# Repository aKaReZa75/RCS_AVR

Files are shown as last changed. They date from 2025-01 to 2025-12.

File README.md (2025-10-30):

# 📲 Relay Control with SMS using an AVR microcontroller  
The RCS_AVR project is an interactive, hands-on initiative focused on remote relay control via SMS.  
It includes components like a Power Supply Unit (PSU) for multiple voltage levels, a GSM Module for SMS command processing, an AVR Microcontroller (ATMEGA328) for control logic, and various inputs and outputs for seamless interaction.  
Communication occurs through protocols like UART.  
This project provides practical insights into embedded systems, covering GSM module integration, power supply management, microcontroller interfacing, remote control mechanisms, and sensor data processing. 
This project serves as an excellent platform for learning and experimenting with embedded systems, offering practical insights into real-world applications. 

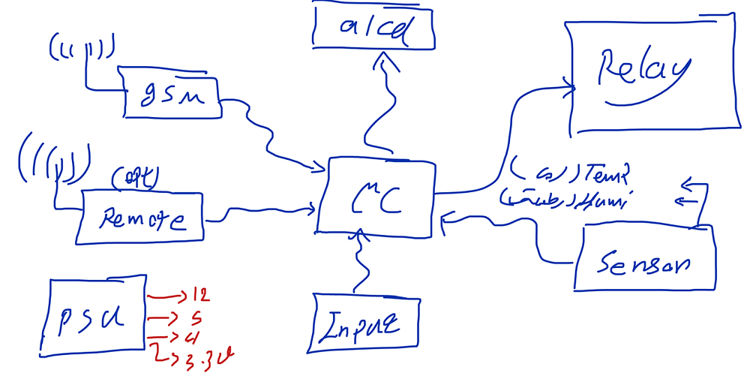
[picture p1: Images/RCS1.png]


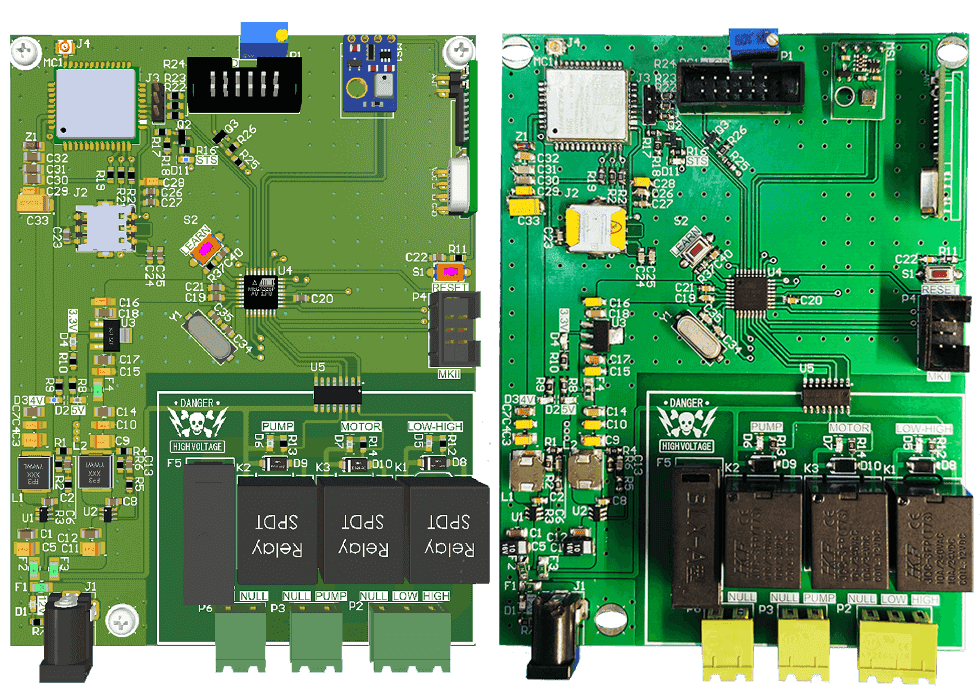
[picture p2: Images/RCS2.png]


<table>
  <tr>
  <td valign="top">
  
  > [!TIP]  
  > If you're looking to better understand how to navigate and use my GitHub repositories — including exploring their structure, downloading or cloning projects, submitting issues, and asking questions,  
  > everything you need is clearly explained in this video:  
  > [aKaReZa 95 - Programming, Git - PART B](https://youtu.be/zYiUItVFRqQ)  
  > Make sure to check it out!
  
  </td>
    <td width="360" valign="middle" style="padding: 0;">
      <a href="https://youtu.be/zYiUItVFRqQ">
       aKaReZa 95 - Programming, Git - PART B Thumbnail
      </a>
    </td>
  </td>
  </tr>

<tr>
  <td valign="top">
  
  > [!IMPORTANT]
  > Begin your embedded systems journey with clarity and purpose. This episode outlines a structured roadmap for mastering microcontrollers, communication protocols, hardware design, and project development.  
  > Learn how to choose your specialization, follow curated playlists, and engage effectively with the community—ideal for learners seeking a scalable, goal-driven path into embedded engineering.  
  > [aKaReZa 124 – Embedded Systems Roadmap](https://youtu.be/3QYfv7A7aMc)  
  > Watch it now to kickstart your journey!
  
  </td>
  <td width="360" valign="middle" style="padding: 0;">
    <a href="https://youtu.be/3QYfv7A7aMc">
      aKaReZa 124 – Embedded Systems Roadmap Thumbnail
    </a>
  </td>
</tr>

  <tr>
  <td colspan="3">

  > [!CAUTION]
  > It is absolutely critical that you carefully read every single word of this document, line by line, to ensure you don't miss any details. Nothing can be overlooked.
      
  </td>
  </tr>  
</table>

### 📋 Additional Details:
| Component | Specification |
|---|---|
| **Microcontroller** | ATMEGA328 |
| **Operating Frequency** | 16MHz |
| **Programming Language**| Embedded C |
| **Compiler** | avr-gcc |
| **Editor** | Visual Studio Code (VsCode) |
| **IDE** | PlatformIO |
| **PCB Design Software** | Altium Designer |
| **Version Control** | Git, GitHub |
| **Communication Module**| GSM (Quectel MC66) |
| **Remote Control** | RXB22 433 MHZ |
| **Display** | Character LCD 16x2 |
| **Output** | Relay, SPDT, 12V, 22X16mm, 240V/7A |
| **Temperature Sensor**  | AHT20 |
| **5V Regulator** | TPS54302 |
| **4V Regulator** | TPS54302 |
| **3.3V Regulator** | AMS1117-3.3V |

# 🔗 Resources
  Here you'll find a collection of useful links and documents related to the RCS_AVR project.  
  These resources include datasheets, tutorials, and essential tools to get you started and guide you through.
  
> [!TIP]
> The resources are detailed in the sections below.  
> To access any of them, simply click on the corresponding blue link.

- [Video PlayList](./Videos.md)
  ---  
  All educational videos related to this topic are available at this link.

- [Altium Library](https://github.com/aKaReZa75/Altium-Library)  
  ---  
   All PCB designs across all repositories and projects are built using this Altium Designer component library. It contains a wide range of verified footprints, schematic symbols, and 3D models, ensuring consistency and accuracy in PCB designs. If you're working on a new PCB, using this library will save you time and minimize errors.

- [PCB & Electronics Design Training](https://github.com/aKaReZa75/PCB)  
  ---  
  This repository is dedicated to **learning PCB design and electronics from scratch**. It covers everything from circuit theory to practical PCB layout techniques, including routing strategies, best practices, and component placement. Whether you're a beginner or an experienced designer, this resource will help you **improve your PCB design skills and create professional-quality boards**.

- [AVR Microcontroller Training](https://github.com/aKaReZa75/AVR)  
  ---  
  This repository is focused on **AVR microcontroller programming**. It covers everything from **basic to advanced concepts**, including peripheral interfacing, timers, interrupts, and communication protocols. Ideal for anyone looking to deepen their knowledge and skills with AVR microcontrollers.

- [Shopping Link](./ShoppingLink.md)  
  ---
  This document provides links to trusted suppliers where you can purchase all the essential components for this project, ensuring quality and reliability.

# 💻 How to Use Git and GitHub
To access the repository files and save them on your computer, there are two methods available:
1. **Using Git Bash and Cloning the Repository**
   - This method is more suitable for advanced users and those familiar with command-line tools.
   - By using this method, you can easily receive updates for the repository.

2. **Downloading the Repository as a ZIP file**
   - This method is simpler and suitable for users who are not comfortable with command-line tools.
   - Note that with this method, you will not automatically receive updates for the repository and will need to manually download any new updates.

## Clone using the URL.
First, open **Git Bash** :
-  Open the folder in **File Explorer** where you want the library to be stored.
-  **Right-click** inside the folder and select the option **"Open Git Bash here"** to open **Git Bash** in that directory.

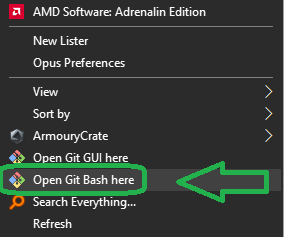
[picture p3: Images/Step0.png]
open Git Bash


> [!NOTE] 
> If you do not see the "Open Git Bash here" option, it means that Git is not installed on your system.  
> You can download and install Git from [this link](https://git-scm.com/downloads).  
> For a tutorial on how to install and use Git, check out [this video](https://youtu.be/BsykgHpmUt8).
  
-  Once **Git Bash** is open, run the following command to clone the repository:

 ```bash
git clone https://github.com/aKaReZa75/RCS_AVR
```
- You can copy the above command by either:
- Clicking on the **Copy** button on the right of the command.
- Or select the command text manually and press **Ctrl + C** to copy.
- To paste the command into your **Git Bash** terminal, use **Shift + Insert**.

Clone the Repository

- Then, press Enter to start the cloning operation and wait for the success message to appear.

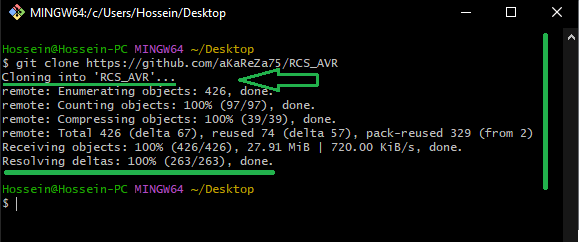
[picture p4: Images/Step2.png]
Open the Library File


> [!IMPORTANT]
> Please keep in mind that the numbers displayed in the image might vary when you perform the same actions.  
> This is because repositories are continuously being updated and expanded. Nevertheless, the overall process remains unchanged.

> [!NOTE]
> Advantage of Cloning the Repository:  
> - **Receiving Updates:** By cloning the repository, you can easily and automatically receive new updates.  
> - **Version Control:** Using Git allows you to track changes and revert to previous versions.  
> - **Team Collaboration:** If you are working on a project with a team, you can easily sync changes from team members and collaborate more efficiently.  

## Download Zip
If you prefer not to use Git Bash or the command line, you can download the repository directly from GitHub as a ZIP file.  
Follow these steps:  
1. Navigate to the GitHub repository page and Locate the Code button:
   - On the main page of the repository, you will see a green Code button near the top right corner.

2. Download the repository:
   - Click the Code button to open a dropdown menu.
   - Select Download ZIP from the menu.

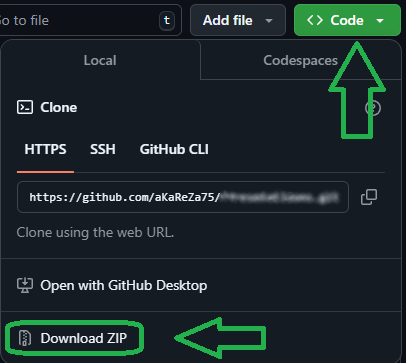
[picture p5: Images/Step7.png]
Download Zip
    

3. Save the ZIP file:
   - Choose a location on your computer to save the ZIP file and click Save.

4. Extract the ZIP file:
   - Navigate to the folder where you saved the ZIP file.
   - Right-click on the ZIP file and select Extract All... (Windows) or use your preferred extraction tool.
   - Choose a destination folder and extract the contents.

5. Access the repository:
   - Once extracted, you can access the repository files in the destination folder.

> [!IMPORTANT]
> - No Updates: Keep in mind that downloading the repository as a ZIP file does not allow you to receive updates.    
>   If the repository is updated, you will need to download it again manually.  
> - Ease of Use: This method is simpler and suitable for users who are not comfortable with Git or command-line tools.

# 📝 How to Ask Questions
If you have any questions or issues, you can raise them through the **"Issues"** section of this repository. Here's how you can do it:  

1. Navigate to the **"Issues"** tab at the top of the repository page.  

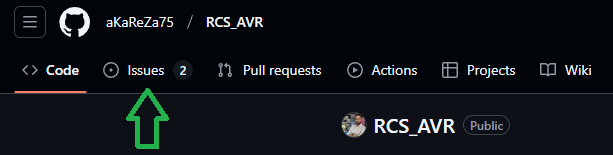
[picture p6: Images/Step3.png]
Issues
  

2. Click on the **"New Issue"** button.  
   
  New Issue

3. In the **Title** field, write a short summary of your issue or question.  

4. In the "Description" field, detail your question or issue as thoroughly as possible. You can use text formatting, attach files, and assign the issue to someone if needed. You can also use text formatting (like bullet points or code snippets) for better readability.  

5. Optionally, you can add **labels**, **type**, **projects**, or **milestones** to your issue for better categorization.  

6. Click on the **"Submit new issue"** button to post your question or issue.
   
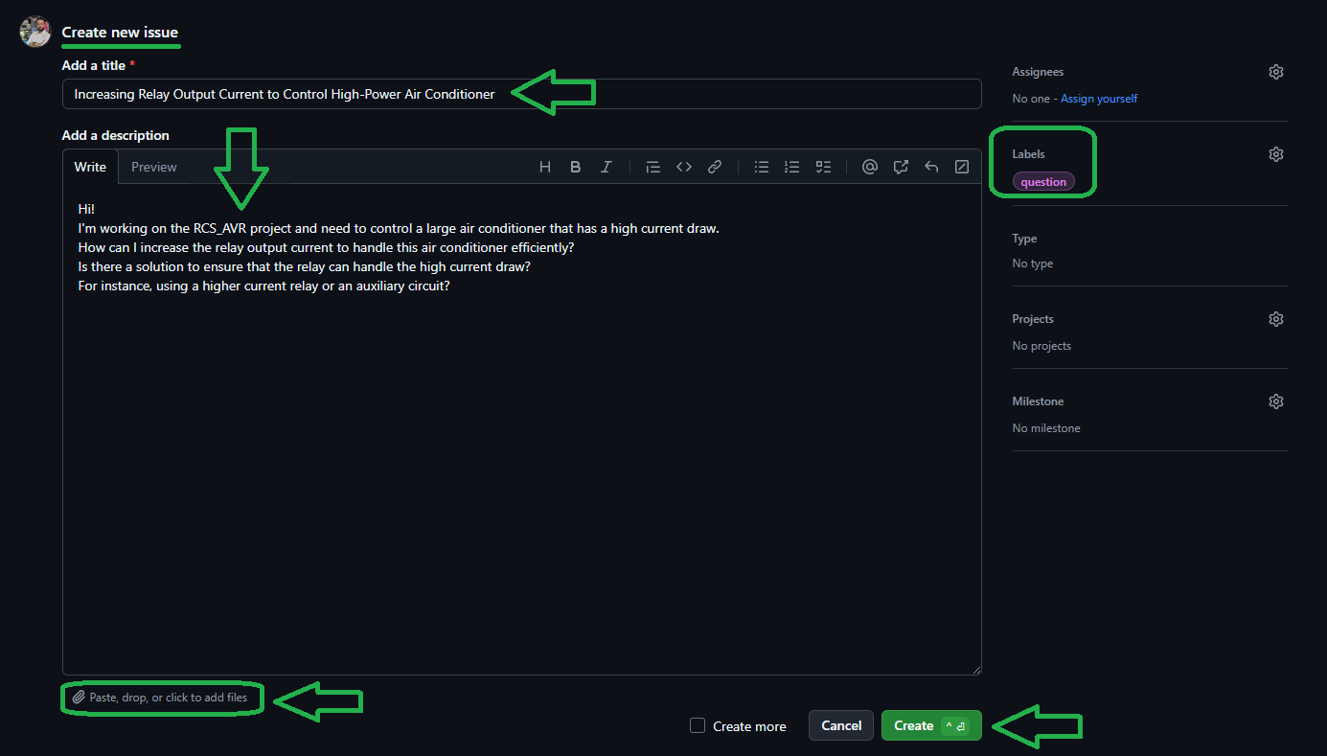
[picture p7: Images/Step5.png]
Submeet New Issue
  

I will review and respond to your issue as soon as possible. Your participation helps improve the repository for everyone!  

> [!TIP]
> - Before creating a new issue, please check the **"Closed"** section to see if your question has already been answered.  
>   Closed section  
> - Write your question clearly and respectfully to ensure a faster and better response.  
> - While the examples provided above are in English, feel free to ask your questions in **Persian (فارسی)** as well.  
> - There is no difference in how they will be handled!  

> [!NOTE]
> Pages and interfaces may change over time, but the steps to create an issue generally remain the same.

# 🤝 Contributing to the Repository
To contribute to this repository, please follow these steps:
1. **Fork the Repository**  
2. **Clone the Forked Repository**  
3. **Create a New Branch**  
4. **Make Your Changes**  
5. **Commit Your Changes**  
6. **Push Your Changes to Your Forked Repository**  
7. **Submit a Pull Request (PR)**  

> [!NOTE]
> Please ensure your pull request includes a clear description of the changes you’ve made.
> Once submitted, I will review your contribution and provide feedback if necessary.

# 🌟 Support Me
If you found this repository useful:
- Subscribe to my [YouTube Channel](https://www.youtube.com/@aKaReZa75).
- Share this repository with others.
- Give this repository and my other repositories a star.
- Follow my [GitHub account](https://github.com/aKaReZa75).

# 📜 License
This project is licensed under the GPL-3.0 License. This license grants you the freedom to use, modify, and distribute the project as long as you:
- Credit the original authors: Give proper attribution to the original creators.
- Disclose source code: If you distribute a modified version, you must make the source code available under the same GPL license.
- Maintain the same license: When you distribute derivative works, they must be licensed under the GPL-3.0 too.
- Feel free to use it in your projects, but make sure to comply with the terms of this license.
  
# ✉️ Contact Me
Feel free to reach out to me through any of the following platforms:
- 📧 [Email: aKaReZa75@gmail.com](mailto:aKaReZa75@gmail.com)
- 🎥 [YouTube: @aKaReZa75](https://www.youtube.com/@aKaReZa75)
- 💼 [LinkedIn: @akareza75](https://www.linkedin.com/in/akareza75)

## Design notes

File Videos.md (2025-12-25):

# Videos
 In this document, you will find videos related to the RCS_AVR project along with their descriptions, which are divided into three categories: 
 - **Hardware design videos**
 - **Assembly and soldering videos**
 - **Coding and testing videos**

```plaintext
RCS, AVR Project
├── PCB
│   ├── [aKaReZa 70 - RCS, AVR - PART A]
│   │     ├─ Kickoff — Conceptual design, enclosure, Git/GitHub.
│   │     └─ Schematic — Altium Designer introduction and setup.
│   │
│   ├── [aKaReZa 71 - RCS, AVR - PART B]
│   │     ├─ Power Supply — 12V, 5V, 4V, 3.3V design.
│   │     └─ Safety — Fusing and voltage indicators.
│   │
│   ├── [aKaReZa 72 - RCS, AVR - PART C]
│   │     ├─ Collaboration — Issues, Pull Requests, Git tools.
│   │     └─ Power — Final regulator setup and LED resistors.
│   │
│   ├── [aKaReZa 73 - RCS, AVR - PART D]
│   │     ├─ Logic & Outputs — ATMega328, Reset, Relays, ULN2003.
│   │     ├─ Protection — Flywheel diode and LED indicators.
│   │     └─ Structure — Hierarchical design + library file export.
│   │
│   ├── [aKaReZa 75 - RCS, AVR - PART E]
│   │     ├─ LCD & Harness — Alphanumeric display and Harness tool.
│   │     ├─ GSM — SIMCard, UART protocol, filters, network LED.
│   │     └─ Review — GitHub Pull Requests and GSM tips.
│   │
│   ├── [aKaReZa 79 - RCS, AVR - PART F]
│   │     ├─ Input — 220V detection and signal handling.
│   │     ├─ Remote Control — Section creation and error fixes.
│   │     └─ Integration — Board shape design + Hamibash feature.
│   │
│   ├── [aKaReZa 81 - RCS, AVR - PART G]
│   │     ├─ Schematic Updates — GitHub issues and fixes.
│   │     ├─ PCB — Component placement and routing.
│   │     └─ Capacitors — Placement technique and performance tip.
│   │
│   └── [aKaReZa 83 - RCS, AVR - PART H]
│         ├─ Routing — Completion and optimization.
│         ├─ Tools — Polygon, Teardrops, Via Stitching.
│         └─ Mounting — Screw placement and final fixes.
│ 
├── Soldering
│   ├── [aKaReZa 100 - RCS, AVR - PART A]
│   │     ├─ Sections — 12V, 5V, 3.3V regulators.
│   │     ├─ MCU — ATMEGA soldering + relay + LCD.
│   │     └─ Testing — Segment-wise validation.
│   │
│   └── [aKaReZa 104 - RCS, AVR - PART B]
│         ├─ LCD Connector — Precision soldering tips.
│         ├─ Components — 4V reg, Quectel M66, SIM filters.
│         └─ Final Test — Complete module evaluation.
│ 
└── Programming
    ├── [aKaReZa 106 - RCS, AVR - PART I]
    │     ├─ PlatformIO — Project setup and structure.
    │     ├─ LCD — HomePage design and initialization.
    │     ├─ Relays — Output pin config and tests.
    │     └─ Control — Modular output handling logic.
    │
    ├── [aKaReZa 109 - RCS, AVR - PART J]
    │     ├─ Control — Output status display on LCD.
    │     ├─ GSM — Signal strength and registration via M66.
    │     ├─ Logic — State machine design.
    │     └─ Interface — Graphical LCD menu implementation.
    │
    ├── [aKaReZa 119 - RCS, AVR - PART K]
    │     ├─ Libraries — Project structure and GSM setup.
    │     ├─ SMS Rx — Parsing incoming messages.
    │     ├─ Format — Suggested SMS command syntax.
    │     ├─ Control — Output switching via SMS.
    │     ├─ Reply — Sending confirmation messages.
    │     ├─ Case Handling — `str_toUpper()` for flexibility.
    │     └─ Stability — Debugging and system reliability.
    │
    ├── [aKaReZa 125 - RCS, AVR - PART L]
    │     ├─ Git — Branch creation and version control.
    │     ├─ State Machine — System behavior management.
    │     ├─ Scheduler — Task configuration and execution.
    │     ├─ Tasks — Output and display routines.
    │     ├─ GSM States — One-time operations and transitions.
    │     └─ Deployment — Pushing changes to GitHub.
    │
    ├── [aKaReZa 128 - RCS, AVR - PART N]
    │   ├─ GSM_Reset — Definition and safe reinitialization flow.
    │   ├─ GSM_StartUp — Sequencing and non-blocking checks.
    │   ├─ LCD Feedback — Live state reflection on display.
    │   ├─ GSM_Init — Resource setup and readiness validation.
    │   └─ GSM_Idle — Event-driven loop and transition rules.
    │
    └── [aKaReZa 132 - RCS, AVR - PART O]
        ├─ Detection — Finding new SMS messages from GSM.
        ├─ GSM_SMS_ParseNumber — Extracting message index.
        ├─ GSM_SMS_ReadContent — Getting sender number and text.
        ├─ GSM_SMS_SendSMS — Reply SMS state machine.
        ├─ LCD — Busy icon, Welcome Page redesign, FW version.
        ├─ Code — Readability and structure improvements.
        └─ Git — Introduction to git merge workflow.
```

## PCB Desing Videos
<table style="border-collapse: collapse;">
  <tr>
    <td valign="top" style="padding: 0 10px;">
      <h3 style="margin: 0;">
        <a href="https://youtu.be/KLH8E3yOOMw">aKaReZa 70 – RCS, AVR - PART A</a>
      </h3>
      <p style="margin: 8px 0 0;">
        This first video in the series covers designing a project from idea to final product, including conceptual design, casing selection, schematic creation in Altium Designer, and more.
      </p>
    </td>
    <td width="360" valign="top" style="padding: 0;">
      <a href="https://youtu.be/KLH8E3yOOMw">
        aKaReZa 70 – RCS, AVR - PART A Thumbnail
      </a>
    </td>
  </tr>

  <tr>
    <td valign="top" style="padding: 0 10px;">
      <h3 style="margin: 0;">
        <a href="https://youtu.be/-EyT4b3-hQU">aKaReZa 71 – RCS, AVR - PART B</a>
      </h3>
      <p style="margin: 8px 0 0;">
        In this video, we design a 12-5-4-3.3V power supply, add fuses, and include voltage indicators.
      </p>
    </td>
    <td width="360" valign="top" style="padding: 0;">
      <a href="https://youtu.be/-EyT4b3-hQU">
        aKaReZa 71 – RCS, AVR - PART B Thumbnail
      </a>
    </td>
  </tr>

  <tr>
    <td valign="top" style="padding: 0 10px;">
      <h3 style="margin: 0;">
        <a href="https://youtu.be/bh53Z6KH728">aKaReZa 72 – RCS, AVR - PART C</a>
      </h3>
      <p style="margin: 8px 0 0;">
        In this video, we review all your Issues and Pull Requests, introduce some useful software, complete the project's power supply section, and discuss upcoming channel content and plans.
      </p>
    </td>
    <td width="360" valign="top" style="padding: 0;">
      <a href="https://youtu.be/bh53Z6KH728">
        aKaReZa 72 – RCS, AVR - PART C Thumbnail
      </a>
    </td>
  </tr>

  <tr>
    <td valign="top" style="padding: 0 10px;">
      <h3 style="margin: 0;">
        <a href="https://youtu.be/vWiSh-8D4kY">aKaReZa 73 – RCS, AVR - PART D</a>
      </h3>
      <p style="margin: 8px 0 0;">
        In this video, after designing the controller and output sections, we learn hierarchical design, create the project hierarchically, and finally generate the project's library file.
      </p>
    </td>
    <td width="360" valign="top" style="padding: 0;">
      <a href="https://youtu.be/vWiSh-8D4kY">
        aKaReZa 73 – RCS, AVR - PART D Thumbnail
      </a>
    </td>
  </tr>

  <tr>
    <td valign="top" style="padding: 0 10px;">
      <h3 style="margin: 0;">
        <a href="https://youtu.be/V0r4XVZA-bk">aKaReZa 75 – RCS, AVR - PART E</a>
      </h3>
      <p style="margin: 8px 0 0;">
        In this video, we cover using character LCDs, the Harness tool in Altium Designer, identifying VCC, VEE, VDD, and VSS pins, connecting a SIM card and UART protocol to a GSM module, adding power filters and a network status LED to the GSM module, and reviewing some GSM module tips. Additionally, we check the raised Pull Requests and Issues.
      </p>
    </td>
    <td width="360" valign="top" style="padding: 0;">
      <a href="https://youtu.be/V0r4XVZA-bk">
        aKaReZa 75 – RCS, AVR - PART E Thumbnail
      </a>
    </td>
  </tr>

  <tr>
    <td valign="top" style="padding: 0 10px;">
      <h3 style="margin: 0;">
        <a href="https://youtu.be/U1JYVCcn27k">aKaReZa 79 – RCS, AVR - PART F</a>
      </h3>
      <p style="margin: 8px 0 0;">
        In this video, we review raised Pull Requests and Issues, organize the project, design the input section and 220V signal detection, design the code-learn remote section, fix errors, resize the board to fit the casing, introduce the "Hami Bash" section, and discuss the idea of casing installation.
      </p>
    </td>
    <td width="360" valign="top" style="padding: 0;">
      <a href="https://youtu.be/U1JYVCcn27k">
        aKaReZa 79 – RCS, AVR - PART F Thumbnail
      </a>
    </td>
  </tr>

  <tr>
    <td valign="top" style="padding: 0 10px;">
      <h3 style="margin: 0;">
        <a href="https://youtu.be/6VrP90s_HFc">aKaReZa 81 – RCS, AVR - PART G</a>
      </h3>
      <p style="margin: 8px 0 0;">
        In this video, we address the issues raised on GitHub, make several schematic changes, place components in the PCB environment, route several sections, and learn a crucial tip about capacitor placement.
      </p>
    </td>
    <td width="360" valign="top" style="padding: 0;">
      <a href="https://youtu.be/6VrP90s_HFc">
        aKaReZa 81 – RCS, AVR - PART G Thumbnail
      </a>
    </td>
  </tr>

  <tr>
    <td valign="top" style="padding: 0 10px;">
      <h3 style="margin: 0;">
        <a href="https://youtu.be/ByZ2kSmf6VU">aKaReZa 83 – RCS, AVR - PART H</a>
      </h3>
      <p style="margin: 8px 0 0;">
        In this video, we continue routing the board. After completing the routes, we learn how to strengthen power paths, place screws on the board, and use the Polygon, Teardrops, and Via stitching tools.
      </p>
    </td>
    <td width="360" valign="top" style="padding: 0;">
      <a href="https://youtu.be/ByZ2kSmf6VU">
        aKaReZa 83 – RCS, AVR - PART H Thumbnail
      </a>
    </td>
  </tr>

  <tr>
    <td valign="top" style="padding: 0 10px;">
      <h3 style="margin: 0;">
        <a href="https://youtu.be/FoJUFKjwWjk">aKaReZa 98 – PCB, Ordering</a>
      </h3>
      <p style="margin: 8px 0 0;">
        In this video, explore essential steps for ordering PCB, from fixing issues before printing, reviewing design rules, error troubleshooting, professional documentation, and learning about local companies and Cheap Project group for seamless PCB manufacturing.
      </p>
    </td>
    <td width="360" valign="top">
      <a href="https://youtu.be/FoJUFKjwWjk">
        aKaReZa 98 – PCB, Ordering Thumbnail
      </a>
    </td>
  </tr>  
</table>

## Assembly and soldering videos
<table style="border-collapse: collapse;">
  <tr>
    <td valign="top" style="padding: 0 10px;">
      <h3 style="margin: 0;">
        <a href="https://youtu.be/UuL0Z89b1r0">aKaReZa 100 – Repair, RCS, AVR - PART A</a>
      </h3>
      <p style="margin: 8px 0 0;">
        Learn the full soldering and assembly process of the RCS-AVR board. This video walks you through every step, including soldering power inputs, voltage regulators (12V, 5V, 3.3V), microcontroller placement, relay and LCD installation, and performing circuit tests after each phase to ensure proper functionality. A must-watch for anyone wanting practical experience in microcontroller board repair and troubleshooting.
      </p>
    </td>
    <td width="360" valign="top">
      <a href="https://youtu.be/UuL0Z89b1r0">
        aKaReZa 100 – Repair, RCS, AVR - PART A Thumbnail
      </a>
    </td>
  </tr>

  <tr>
    <td valign="top" style="padding: 0 10px;">
      <h3 style="margin: 0;">
        <a href="https://youtu.be/i9ef0sJyjoc">aKaReZa 104 – Repair, RCS AVR Soldering - PART B</a>
      </h3>
      <p style="margin: 8px 0 0;">
        Continue soldering the RCS-AVR project with a focus on communication modules. This video covers LCD connector soldering, 4V regulator installation, Quectel M66 module assembly, SIM card connector setup, remaining component soldering, and final system testing to ensure everything functions correctly. Perfect for microcontroller board assembly and troubleshooting enthusiasts.
      </p>
    </td>
    <td width="360" valign="top">
      <a href="https://youtu.be/i9ef0sJyjoc">
        aKaReZa 104 – Repair, RCS AVR Soldering - PART B Thumbnail
      </a>
    </td>
  </tr> 
</table>

## Coding and testing videos
<table style="border-collapse: collapse;">
  <tr>
    <td valign="top" style="padding: 0 10px;">
      <h3 style="margin: 0;">
        <a href="https://youtu.be/397Jk0z9aTY">aKaReZa 106 – RCS, AVR - PART I</a>
      </h3>
      <p style="margin: 8px 0 0;">
        Start coding the RCS-AVR project using PlatformIO, with a focus on LCD initialization, homepage design, relay control, and hardware interaction. This video lays the groundwork for structured, modular AVR programming tailored to practical embedded systems development.
      </p>
    </td>
    <td width="360" valign="top">
      <a href="https://youtu.be/397Jk0z9aTY">
        aKaReZa 106 – RCS, AVR - PART I Thumbnail
      </a>
    </td>
  </tr>

  <tr>
    <td valign="top" style="padding: 0 10px;">
      <h3 style="margin: 0;">
        <a href="https://youtu.be/tSlz7DpWGOs">aKaReZa 109 – RCS, AVR - PART J</a>
      </h3>
      <p style="margin: 8px 0 0;">
        Advance the RCS-AVR project by implementing output control, reading signal strength, managing network registration, and designing LCD menus. This video explores state machines, real-time status display, and software-hardware interaction—ideal for building smart embedded systems.
      </p>
    </td>
    <td width="360" valign="top">
      <a href="https://youtu.be/tSlz7DpWGOs">
        aKaReZa 109 – RCS, AVR - PART J Thumbnail
      </a>
    </td>
  </tr>

  <tr>
    <td valign="top" style="padding: 0 10px;">
      <h3 style="margin: 0;">
        <a href="https://youtu.be/OboAPzh3QSU">aKaReZa 119 – RCS, AVR - PART K</a>
      </h3>
      <p style="margin: 8px 0 0;">
        Build SMS-based control systems with AVR and the Quectel M66 module. This video covers message parsing, output control, reply generation, and case-insensitive command handling using <code>str_toUpper()</code>—a practical guide for robust GSM integration in embedded projects.
      </p>
    </td>
    <td width="360" valign="top">
      <a href="https://youtu.be/OboAPzh3QSU">
        aKaReZa 119 – RCS, AVR - PART K Thumbnail
      </a>
    </td>

  <tr>
    <td valign="top" style="padding: 0 10px;">
      <h3 style="margin: 0;">
        <a href="https://youtu.be/RPZP1AIJVvo">aKaReZa 125 – RCS, AVR - PART L</a>
      </h3>
      <p style="margin: 8px 0 0;">
        Advance your embedded software development workflow with Git and structured logic. This episode introduces Git branching for safe feature development, implements a robust State Machine, configures a Scheduler, and defines tasks for output and display control. It also reviews GSM module states and one-time operations, culminating in a clean GitHub push—ideal for building scalable, maintainable AVR-based systems.
      </p>
    </td>
    <td width="360" valign="top">
      <a href="https://youtu.be/RPZP1AIJVvo">
        aKaReZa 125 – RCS, AVR - PART L Thumbnail
      </a>
    </td>
  </tr>

  <tr style="background-color: #f9f9f9;">
    <td valign="top" style="padding: 0 10px;">
      <h3 style="margin: 0;">
        <a href="https://youtu.be/RqF51kzmc10">aKaReZa 128 – RCS, AVR - PART N</a>
      </h3>
      <p style="margin: 8px 0 0;">
        Deepen your understanding of <strong>State Machines in embedded systems</strong> with this AVR-based RCS project episode. You’ll learn how to implement and manage <strong>GSM_Reset, GSM_StartUp, GSM_Init, and GSM_Idle states</strong>, while reflecting transitions on the LCD. The tutorial emphasizes <strong>non-blocking code design principles</strong>, making it a crucial step toward building smarter, more reliable GSM-driven control systems.
      </p>
    </td>
    <td width="360" valign="top">
      <a href="https://youtu.be/RqF51kzmc10">
        aKaReZa 128 – RCS, AVR - PART N Thumbnail
      </a>
    </td>
  </tr>

  <tr style="background-color: #f9f9f9;">
    <td valign="top" style="padding: 0 10px;">
      <h3 style="margin: 0;">
        <a href="https://youtu.be/P0FgmPWP3M4">aKaReZa 132 – RCS, AVR - PART O</a>
      </h3>
      <p style="margin: 8px 0 0;">
        Implement fully non‑blocking <strong>SMS receive/send state machines</strong> in the RCS‑AVR project. This episode walks through detecting new messages, parsing the SMS index, extracting the sender’s number and text, and sending replies through the GSM module. You’ll also enhance the LCD interface with <strong>custom characters</strong>, redesign the <strong>Welcome Page</strong>, display the firmware version, and learn how to integrate changes using <strong>git merge</strong> for a cleaner workflow.
      </p>
    </td>
    <td width="360" valign="middle">
      <a href="https://youtu.be/P0FgmPWP3M4">
        aKaReZa 132 – RCS, AVR - PART O Thumbnail
      </a>
    </td>
  </tr>
  
</table>

# 🌟 Support Me
If you found this repository useful:
- Subscribe to my [YouTube Channel](https://www.youtube.com/@aKaReZa75).
- Share this repository with others.
- Give this repository and my other repositories a star.
- Follow my [GitHub account](https://github.com/aKaReZa75).

# ✉️ Contact Me
Feel free to reach out to me through any of the following platforms:
- 📧 [Email: aKaReZa75@gmail.com](mailto:aKaReZa75@gmail.com)
- 🎥 [YouTube: @aKaReZa75](https://www.youtube.com/@aKaReZa75)
- 💼 [LinkedIn: @akareza75](https://www.linkedin.com/in/akareza75)

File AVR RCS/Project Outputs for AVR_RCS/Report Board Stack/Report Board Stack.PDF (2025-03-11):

# Board Stack Report

Stack Up | Layer Stack
Layer | Board Layer Stack | Name | Material | Thickness Constant Dk | | | Coverlay expansion | Orientation | Copper Orientation
1 | | Top Overlay | | 0mm
2 | | Top Solder | Solder Resist | 0.01016mm | 3.5 | 3.5 0mm
3 | | Top Layer | | 0.03556mm | | | | BodyUp | Above
4 | | Dielectric 1 | FR-4 | 1.5mm | 4.8 | 4.8
5 | | Bottom Layer | | 0.03556mm | | | | BodyDown | Below
6 | | Bottom Solder | Solder Resist | 0.01016mm | 3.5 | 3.5 0mm
7 | | Bottom Overlay | | 0mm
| Height : 1.59144mm

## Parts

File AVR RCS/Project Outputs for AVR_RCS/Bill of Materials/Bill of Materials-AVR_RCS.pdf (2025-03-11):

Altium Limited Confidential | 3/11/2025 | Page 1

# Bill of Materials

Title: Bill of Materials for Project [AVR_RCS.PrjPcb] (No PCB Document Selected) Project: AVR RCS
Company github.com/aKaReZa75
Variant: None
Revision: 1.0
Inflow | LibRef | Footprint | Value | Rating | Package | Type | Description | Comment | Quantity
inflow? | Cap_Multi_SMD_100nF_0805 | CAP 0805/2012 | 100n | 50V | 0805 | MultiLayer | Bipolar ceramic capacitor SMD | 100n | 8
inflow? | Cap_Multi_SMD_100nF_1206 | CAP 1206/3216 | 100n | 50V | 1206 | MultiLayer | Bipolar ceramic capacitor SMD | 100n | 7
inflow? | Cap_Multi_SMD_0805 | CAP 0805/2012 | 22p | Rating? | 0805 | MultiLayer | Bipolar ceramic capacitor SMD | 22p | 2
inflow? | Cap_Multi_SMD_0805 | CAP 0805/2012 | 33p | Rating? | 0805 | MultiLayer | Bipolar ceramic capacitor SMD | 33p | 4
inflow? | Cap_Multi_SMD_0805 | CAP 0805/2012 | 68p | Rating? | 0805 | MultiLayer | Bipolar ceramic capacitor SMD | 68p | 2
inflow? | Cap_Multi_SMD_1206 | CAP 1206/3216 | 10p | 50V | 1206 | MultiLayer | Bipolar ceramic capacitor SMD | 10p | 1
inflow? | Cap_Multi_SMD_1206 | CAP 1206/3216 | 33p | 50V | 1206 | MultiLayer | Bipolar ceramic capacitor SMD | 33p | 1
inflow? | Cap_Tantalum | SMT_C_Tantalum_A | 1u | 6.3V | SMD-A | Tantalum | Tantalum Capacitor,TAJ Series-SMD | 1u | 2
inflow? | Cap_Tantalum | SMT_C_Tantalum_A | 10u | 6.3v | Package? | Tantalum | Tantalum Capacitor,TAJ Series-SMD | 10u | 3
inflow? | Cap_Tantalum | SMT_C_Tantalum_B | 10u | 25v | Package? | Tantalum | Tantalum Capacitor,TAJ Series-SMD | 10u | 2
inflow? | Cap_Tantalum | SMT_C_Tantalum_A | 22u | 6.3v | Package? | Tantalum | Tantalum Capacitor,TAJ Series-SMD | 22u | 1
inflow? | Cap_Tantalum | SMT_C_Tantalum_B | 47u | 6.3v | Package? | Tantalum | Tantalum Capacitor,TAJ Series-SMD | 47u | 2
inflow? | Cap_Tantalum | SMT_C_Tantalum_C | 100u | 6.3V | SMD-C | Tantalum | Tantalum Capacitor,TAJ Series-SMD | 100u | 1
7152 | Con_MPH_3x1_V_THT_2.54 | HDR_THT_3M_2.54mm | 3 | Rating? | Package? | Type? | Header, single row, 3 pin | 3 | 1
inflow? | Con_Power_2 | Phoenix_2PIN_RA_P5.08mm | 2'Pin | Rating? | Package? | Type? | Power Connector 2'Pin | 2'Pin | 2
inflow? | Con_Power_3 | Phoenix_3PIN_RA_P5.08mm | Value? | 3b | Dip | Type? | Power Connector 3'Pin | Value? | 1
6127 | Con_Power_Jack | Power Jack BIG | Female | Rating? | Package? | Type? | Power Jack | Female | 1
inflow? | Con_Prog_MKII_ISP | IDC_2X3 | 3x2 | Rating? | Package? | Type? | 6 Pin Standard ISP Header For MKII | 3x2 | 1
inflow? | Con_RF_U.FL | IPEX-3x3mm | U.FL | Rating? | SMD | RF | U.FL | U.FL | 1
inflow? | Con_Socket_SimCard_1 | GCT_SIM8051_Plastik | 6'Pin | Rating? | SMD | Nano | Nano SimCard Holder 6P | 6'Pin | 1
1506 | IC_Driver_ULN2003 | SO16_M | ULN2003 | Rating? | SO-16 | Driver | Seven darlington array drivers | ULN2003 | 1
inflow? | IC_MCU_ATmega328P_SMD | ATMEGA328 | ATmega328P Rating? | | Package? | Type? | 8-Bit AVR Microcontroller with 32K | ATmega328P | 1
5217 | IC_Reg_AMS1117_3.3 | SOT223_M | 3.3V | 1A | SOT223 | LDO | 1'A Positive voltage regulator | 3.3V | 1
inflow? | IC_Reg_TPS54302 | TPS54302 | Value? | S | SOT-23-6 | Switching | 3'A Synchronous Step-Down Converter | Value? | 2
inflow? | Ind_SMD | L_7 | 10u | 3.8A | Package? | Type? | Inductor | 10u | 2
inflow? | ModSen_AHT20 | AHT20 | AHT20 | Rating? | Dip | Air T&H | Air Temperature and Humidity Sensor | AHT20 | 1
inflow? | ModSen_Com_M66 | m66 | M66 | Rating? | Dip | GSM-GPRS | Quectel GSM/GPRS Module | M66 | 1
8251 | ModSen_Com_RXB22_433 | RF_ETRXB | RXB22 | 433M | Dip | Learning | JMR RXB22 433MHz ASK | RXB22 | 1
8116 | ModSen_LCD_CH_16x2_Box | BOX-HDR-2x6-2.54mm-S | 16x2 | Rating? | Dip | Alphanumeric | Alphanumeric LCD character | 16x2 | 1
inflow? | Other_Elec_Fuse_SMD | 1206_F | 0.5A | Rating? | 1206 | Fast | Short circiut protection | 0.5A | 1
inflow? | Other_Elec_Fuse_SMD | 1206_F | 1A | Rating? | 1206 | Fast | Short circiut protection | 1A | 1
inflow? | Other_Elec_Fuse_SMD | 1206_F | 2A | Rating? | 1206 | Fast | Short circiut protection | 2A | 1
inflow? | Other_Elec_Fuse_SMD | 1206_F | 3A | Rating? | 1206 | Fast | Short circiut protection | 3A | 1
inflow? | Other_Elec_Fuse_THT | FUSE_BLX_20x5 | 5A | Rating? | Package? | Type? | Short circiut protection | 5A | 1
inflow? | Other_Elec_Xtal_SMD | Crystal SMD | 12M | Rating? | SMD | Quartz | Crystal Oscillator | 12M | 1
8243 | Other_Mech_Screw | SCREW-M3 | M3 | Rating? | Package? | Screw | Board Screw With Spacer | M3 | 3
inflow? | Res_Multi | Multi turn 01 | 10K | Rating? | Package? | Type? | Multi Turn | 10K | 1
inflow? | Res_SMD_0805 | RES 0805 (2012X06L) | 1K | 0.125W | 0805 | 10% | Resistor | 1K | 3
inflow? | Res_SMD_0805 | RES 0805 (2012X06L) | 1.8K | 0.125W | 0805 | 10% | Resistor | 1.8K | 5
inflow? | Res_SMD_0805 | RES 0805 (2012X06L) | 4.7K | 0.125W | 0805 | 10% | Resistor | 4.7K | 4
inflow? | Res_SMD_0805 | RES 0805 (2012X06L) | 5.6K | 0.125W | 0805 | 10% | Resistor | 5.6K | 1
inflow? | Res_SMD_0805 | RES 0805 (2012X06L) | 10K | 0.125W | 0805 | 10% | Resistor | 10K | 2
inflow? | Res_SMD_0805 | RES 0805 (2012X06L) | 13.7K | 0.125W | 0805 | 1% | Resistor | 13.7K | 1
inflow? | Res_SMD_0805 | RES 0805 (2012X06L) | 17.8K | 0.125W | 0805 | 1% | Resistor | 17.8K | 1
inflow? | Res_SMD_0805 | RES 0805 (2012X06L) | 22b | 0.125W | 0805 | 10% | Resistor | 22b | 3
inflow? | Res_SMD_0805 | RES 0805 (2012X06L) | 47K | 0.125W | 0805 | 10% | Resistor | 47K | 2
inflow? | Res_SMD_0805 | RES 0805 (2012X06L) | 49.9b | 0.125W | 0805 | 1% | Resistor | 49.9b | 2
inflow? | Res_SMD_0805 | RES 0805 (2012X06L) | 100b | 0.125W | 0805 | 10% | Resistor | 100b | 2
inflow? | Res_SMD_0805 | RES 0805 (2012X06L) | 100K | 0.125W | 0805 | 1% | Resistor | 100K | 2
inflow? | Res_SMD_0805 | RES 0805 (2012X06L) | 220b | 0.125W | 0805 | 10% | Resistor | 220b | 1
inflow? | Res_SMD_0805 | RES 0805 (2012X06L) | 680b | 0.125W | 0805 | 10% | Resistor | 680b | 1
inflow? | Semi_BJT_BC817 | SOT23_N | NPN | Rating? | Package? | Type? | NPN General purpose Transistor | NPN | 2
inflow? | Semi_Diod_Sch_1N5819_SMD | 430X270D | 1N5819 | Rating? | SMA | Schottky | Schottky Rectifiers | 1N5819 | 3
inflow? | Semi_Diod_TVS_SMF05 | SC70-5_N | SMF-05 | Rating? | SC70-5 | TVS | TVS Diode Array | SMF-05 | 1
inflow? | Semi_Diod_Zener_SMD | SOD80, LL-34 | 5.1V | 0.5W | SOD-80 | Zener | Zener Diode | 5.1V | 1
inflow? | Semi_LED_SMD | LED 0805/2012 BLUE | Blue | Rating? | Package? | LED | LED | Blue | 2
inflow? | Semi_LED_SMD | LED 0805/2012 GREEN | Green | Rating? | Package? | LED | LED | Green | 4
inflow? | Semi_LED_SMD | LED 0805/2012 RED | Red | Rating? | Package? | LED | LED | Red | 1
inflow? | Semi_LED_SMD | LED 0805/2012 YELLOW | Yellow | Rating? | Package? | LED | LED | Yellow | 1
8260 | SW_PushButton_2_SMD | SW_PB_SMD_2PIN_SPST_6X | PB | 2b | SMD | Vertical | SMT Tactile ‎Switch | PB | 2
inflow? | SW_Relay_SPDT | Relay 18.85x15.35x15.70 | 12V | Rating? | Dip | SPDT | SPDT Relay | 12V | 3
Approved Notes | | | | | | | | | 115

3/11/2025 12:51 PM
Hossein Bagheri

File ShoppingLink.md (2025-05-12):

# 📦 Components Purchase Links
This section provides a comprehensive list of components required for the "Relay Control with SMS using an AVR microcontroller" project.
Each item includes direct purchase links from reliable Iranian electronics suppliers, with recommended quantities for both essential needs and future prototyping.

## Capacitor
- [ ] [**Cap_0805_22p**](https://lionelectronic.ir/products/1950-TCC0805COG220J500BT) Quantity: 2, Prefer: 25, Supplier: LionElectronic
- [ ] [**Cap_0805 33p**](https://lionelectronic.ir/products/1951-TCC0805COG330J500BT) Quantity: 4, Prefer: 25, Supplier: LionElectronic
- [ ] [**Cap_0805_68p**](https://lionelectronic.ir/products/1954-0805CG680J500NT) Quantity: 2, Prefer: 25, Supplier: LionElectronic
- [ ] [**Cap_0805_100n**](https://lionelectronic.ir/products/2791-CL21B104KBCNNNC) Quantity: 8, Prefer: 25, Supplier: LionElectronic
- [ ] [**Cap_1206_10p**](https://lionelectronic.ir/products/1991-1206CG100J500NT) Quantity: 1, Prefer: 25, Supplier: LionElectronic  
- [ ] [**Cap_1206_33p**](https://lionelectronic.ir/products/1994-TCC1206C0G330J500DT) Quantity: 1, Prefer: 25, Supplier: LionElectronic  
- [ ] [**Cap_1206_100n**](https://lionelectronic.ir/products/5156-C3216NP01H104J160AA) Quantity: 7, Prefer: 25, Supplier: LionElectronic
- [ ] [**Cap_Tantal_1u_16V_A**](https://lionelectronic.ir/products/2037-TAJA105K016RNJ) Quantity: 2, Prefer: 5, Supplier: LionElectronic **(Instead of: Cap_Tantal_1u_6.3V_A)**
- [ ] [**Cap_Tantal_10u_10V_A**](https://lionelectronic.ir/products/2046-TAJA106K010RNJ) Quantity: 3, Prefer: 10, Supplier: LionElectronic **(Instead of: Cap_Tantal_10u_6.3V_A)**
- [ ] [**Cap_Tantal_10u_25V_B**](https://lionelectronic.ir/products/1037-TAJB106K025RNJ) Quantity: 2, Prefer: 5, Supplier: LionElectronic
- [ ] [**Cap_Tantal_22u_6.3V_A**](https://lionelectronic.ir/products/2051-TAJA226M006RNJ) Quantity: 1, Prefer: 5, Supplier: LionElectronic 
- [ ] [**Cap_Tantal_47u_6.3V_A**](https://lionelectronic.ir/products/2056-TAJA476K006RNJ) Quantity: 2, Prefer: 5, Supplier: LionElectronic 
- [ ] [**Cap_Tantal_100u_6.3V_B**](https://lionelectronic.ir/products/3312-T520B107M006ATE040) Quantity: 1, Prefer: 5, Supplier: LionElectronic 

## Connector
- [ ] [**Power_Jack**](https://lionelectronic.ir/products/4704-DC005) Quantity: 2, Prefer: 25, Supplier: LionElectronic  
- [ ] [**Con_Phonix_3Pin**](https://lionelectronic.ir/products/6050-KF2EDGR%2BK-5.08-3P) Quantity: 1, Prefer: 5, Supplier: LionElectronic
- [ ] [**Con_Phonix_2Pin**](https://lionelectronic.ir/products/6049-KF2EDGR%2BK-5.08-2P) Quantity: 2, Prefer: 5, Supplier: LionElectronic
- [ ] [**Con_BoxHeadr_2x8**](https://roboeq.ir/products/detail/1504020/%D8%A8%D8%A7%DA%A9%D8%B3-%D9%87%D8%AF%D8%B1-8-2-BOX-HEADER-%D8%B5%D8%A7%D9%81/) Quantity: 1, Prefer: 5, Supplier: RoboEQ  
- [ ] [**Con_IDC_2x8**](https://roboeq.ir/products/detail/1504003/%D8%A2%DB%8C-%D8%AF%DB%8C-%D8%B3%DB%8C-IDC-2-8/) Quantity: 1, Prefer: 5, Supplier: RoboEQ  
- [ ] [**Con_BoxHeadr_2x3**](https://roboeq.ir/products/detail/1504056/%D8%A8%D8%A7%DA%A9%D8%B3-%D9%87%D8%AF%D8%B1-3-2-BOX-HEADER-%D8%B5%D8%A7%D9%81/) Quantity: 1, Prefer: 5, Supplier: RoboEQ  
- [ ] [**Con_IDC_2x3**](https://roboeq.ir/products/detail/1504059/%D8%A2%DB%8C-%D8%AF%DB%8C-%D8%B3%DB%8C-IDC-2-3/) Quantity: 1, Prefer: 5, Supplier: RoboEQ  
- [ ] [**Flat Cable**](https://roboeq.ir/products/detail/1301002/%DA%A9%D8%A7%D8%A8%D9%84-20-%D8%B1%D8%B4%D8%AA%D9%87-%D9%81%D9%84%D8%AA/) Quantity: 0.2, Prefer: 1, Supplier: RoboEQ  
- [ ] [**Simcard_Nano**](https://lionelectronic.ir/products/4593-SI107C-08200) Quantity: 1, Prefer: 1, Supplier: LionElectronic  
- [ ] [**Male_PinHeader**](https://lionelectronic.ir/products/5356-PLS-2.54-1X40GF) Quantity: 0.1, Prefer: 1, Supplier: LionElectronic  
- [ ] [**uFL**](https://lionelectronic.ir/products/5100-BWIPX-1-001E-) Quantity: 1, Prefer: 5, Supplier: LionElectronic  
- [ ] [**uFL to SMA**](https://roboeq.ir/products/detail/1509123/%DA%A9%D8%A7%D9%86%DA%A9%D8%AA%D9%88%D8%B1-UFL-%D8%A8%D9%87-SMA-%D9%85%D8%A7%D8%AF%DA%AF%DB%8C-%D8%B7%D9%88%D9%84-15-%D8%B3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) Quantity: 1, Prefer: 1, Supplier: RoboEQ  

## Integrated Circuit
- [ ] [**IC_ATMEGA328P**](https://lionelectronic.ir/products/293-ATMEGA328P-AU) Quantity: 1, Prefer: 1, Supplier: LionElectronic  
- [ ] [**IC_ULN2003**](https://lionelectronic.ir/products/1506-ULN2003D1013TR) Quantity: 1, Prefer: 5, Supplier: LionElectronic  
- [ ] [**Reg_TPS54302DDCR**](https://lionelectronic.ir/products/2487-TPS54302DDCR) Quantity: 2, Prefer: 5, Supplier: LionElectronic  
- [ ] [**Reg_AMS1117-3.3**](https://lionelectronic.ir/products/868-AMS1117-3.3) Quantity: 1, Prefer: 5, Supplier: LionElectronic  

## Inductor
- [ ] [**Ind_10u_3.8A**](https://lionelectronic.ir/products/4357-SPM6530T-100M) Quantity: 2, Prefer: 5, Supplier: LionElectronic

## Module and Sensor
- [ ] [**AHT20**](https://roboeq.ir/products/detail/0509020/%D9%85%D8%A7%DA%98%D9%88%D9%84-%D8%B3%D9%86%D8%B3%D9%88%D8%B1-%D8%AF%D9%85%D8%A7-%D9%88-%D8%B1%D8%B7%D9%88%D8%A8%D8%AA-AHT2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) Quantity: 1, Prefer: 1, Supplier: RoboEQ
- [ ] [**Quectel M66**](https://shop.sisoog.com/product/%D9%85%D8%A7%DA%98%D9%88%D9%84-m66fb-%DA%A9%D9%88%DB%8C%DA%A9%D8%AA%D9%84/) Quantity: 1, Prefer: 1, Supplier: Sisog
- [ ] [**GSM Anntena**](https://roboeq.ir/products/detail/0502052/%D8%A2%D9%86%D8%AA%D9%86-GSM-%D8%B1%D8%A7%DB%8C%D8%AA-5-%D8%B3%D8%A7%D9%86%D8%AA%DB%8C-%D9%85%D8%AA%D8%B1/) Quantity: 1, Prefer: 1, Supplier: RoboEQ  
- [ ] [**LCD_CH_16x2**](https://lionelectronic.ir/products/994-JHD659-162A-B-W) Quantity: 1, Prefer: 1, Supplier: LionElectronic
- [ ] [**RXB22**](https://roboeq.ir/products/detail/0501141/%D9%85%D8%A7%DA%98%D9%88%D9%84-%DA%AF%DB%8C%D8%B1%D9%86%D8%AF%D9%87-ASK-%D9%81%D8%B1%DA%A9%D8%A7%D9%86%D8%B3-433-%D9%85%DA%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) Quantity: 1, Prefer: 1, Supplier: RoboEQ  

## Other
- [ ] [**Adaptor12V-3A**](https://eshop.eca.ir/%D8%A2%D8%AF%D8%A7%D9%BE%D8%AA%D9%88%D8%B1/1596-%D8%A2%D8%AF%D8%A7%D9%BE%D8%AA%D9%88%D8%B1-12-%D9%88%D9%84%D8%AA-3-%D8%A2%D9%85%D9%BE%D8%B1-%D8%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) Quantity: 1, Prefer: 1, Supplier: ECA  
- [ ] [**BMW 50006-A1**](https://bahar-enclosure.ir/product/bmw-50006-a1/) Quantity: 1, Prefer: 1, Supplier: Bahar
- [ ] [**Fuse_1206_0.5A**](https://lionelectronic.ir/products/1891-JFC1206-0500FS-63V-0.5A) Quantity: 1, Prefer: 5, Supplier: LionElectronic  
- [ ] [**Fuse_1206_1A**](https://lionelectronic.ir/products/1892-JFC1206-1100FS-63V-1A) Quantity: 1, Prefer: 5, Supplier: LionElectronic  
- [ ] [**Fuse_1206_2A**](https://lionelectronic.ir/products/1893-JFC1206-1200FS-63V-2A) Quantity: 1, Prefer: 5, Supplier: LionElectronic
- [ ] [**Fuse_1206_3A**](https://lionelectronic.ir/products/1894-JFC1206-1300FS-63V-3A) Quantity: 1, Prefer: 5, Supplier: LionElectronic
- [ ] [**Fuse_5A**](https://roboeq.ir/products/detail/0320015/%D9%81%DB%8C%D9%88%D8%B2-%D8%B4%DB%8C%D8%B4%D9%87-%D8%A7%DB%8C-5-%D8%A2%D9%85%D9%BE%D8%B1-5x20/) Quantity: 1, Prefer: 5, Supplier: RoboEQ
- [ ] [**Fuse_Holder**](https://roboeq.ir/products/detail/0320002/%D8%AC%D8%A7%D9%81%DB%8C%D9%88%D8%B2%DB%8C-%DA%A9%D9%88%DA%86%DA%A9-%D8%AF%D8%B1%D8%A8-%D8%AF%D8%A7%D8%B1/) Quantity: 1, Prefer: 5, Supplier: RoboEQ
- [ ] [**Crystal 16MHz**](https://lionelectronic.ir/products/2101-XTAL-16MHZ%28HC-49SMD%29) Quantity: 1, Prefer: 5, Supplier: LionElectronic
- [ ] [**M3_Screw**](https://lionelectronic.ir/products/5042-M3x6-Screw) Quantity: 3, Prefer: 25, Supplier: LionElectronic

## Resistor
- [ ] [**Res_0805_22b**](https://lionelectronic.ir/products/1553-0805W8J0220T5E) Quantity: 3, Prefer: 25, Supplier: LionElectronic  
- [ ] [**Res_0805_49.9b**](https://lionelectronic.ir/products/4246-0805W8F499JT5E) Quantity: 2, Prefer: 25, Supplier: LionElectronic  
- [ ] [**Res_0805_100b**](https://lionelectronic.ir/products/1561-0805W8J0101T5E) Quantity: 2, Prefer: 25, Supplier: LionElectronic  
- [ ] [**Res_0805_220b**](https://lionelectronic.ir/products/1565-SER0805J220R) Quantity: 1, Prefer: 25, Supplier: LionElectronic  
- [ ] [**Res_0805_680b**](https://lionelectronic.ir/products/1571-0805W8J0681T5E) Quantity: 1, Prefer: 25, Supplier: LionElectronic
- [ ] [**Res_0805_1K**](https://lionelectronic.ir/products/1573-RS-05K102JT) Quantity: 3, Prefer: 25, Supplier: LionElectronic  
- [ ] [**Res_0805_1.8K**](https://lionelectronic.ir/products/1576-0805W8J0182T5E) Quantity: 5, Prefer: 25, Supplier: LionElectronic
- [ ] [**Res_0805_4.7K**](https://lionelectronic.ir/products/1581-SER0805J4K7) Quantity: 4, Prefer: 25, Supplier: LionElectronic 
- [ ] [**Res_0805_5.6K**](https://lionelectronic.ir/products/1582-0805W8J0562T5E) Quantity: 1, Prefer: 25, Supplier: LionElectronic 
- [ ] [**Res_0805_10K**](https://lionelectronic.ir/products/1585-SCR0805J10K) Quantity: 2, Prefer: 25, Supplier: LionElectronic
- [ ] [**Res_0805_13K**](https://lionelectronic.ir/products/1453-0805W8F1302T5E) Quantity: 1, Prefer: 25, Supplier: LionElectronic **(Instead of: Res_0805_13.7K)**
- [ ] [**Res_0805_18K**](https://lionelectronic.ir/products/5463-0805W8F1782T5E) Quantity: 1, Prefer: 25, Supplier: LionElectronic **(Instead of: Res_0805_17.8K)**
- [ ] [**Res_0805_47K**](https://lionelectronic.ir/products/1593-SER0805J47K) Quantity: 2, Prefer: 25, Supplier: LionElectronic
- [ ] [**Res_0805_100K**](https://lionelectronic.ir/products/1474-RS-05K1003FT) Quantity: 2, Prefer: 25, Supplier: LionElectronic
- [ ] [**Res_0805_130K**](https://lionelectronic.ir/products/1477-0805W8F1303T5E) Quantity: 1, Prefer: 25, Supplier: LionElectronic
- [ ] [**Res_Multi_10K**](https://lionelectronic.ir/products/3235-3296W-1-103LF) Quantity: 1, Prefer: 5, Supplier: LionElectronic

## Semiconductore
- [ ] [**Semi_BJT_BC817**](https://lionelectronic.ir/products/134-BC817-40) Quantity: 2, Prefer: 10, Supplier: LionElectronic 
- [ ] [**Semi_Diod_TVS_SMF05**](https://lionelectronic.ir/products/121-SMF05C.TCT) Quantity: 1, Prefer: 5, Supplier: LionElectronic 
- [ ] [**Semi_Diod_Zener_SMD**](https://lionelectronic.ir/products/2359-ZMM5V1) Quantity: 1, Prefer: 5, Supplier: LionElectronic 
- [ ] [**Semi_1N5819**](https://roboeq.ir/products/detail/0304143/%D8%AF%DB%8C%D9%88%D8%AF-%D8%B4%D8%A7%D8%AA%DA%A9%DB%8C-1-%D8%A2%D9%85%D9%BE%D8%B1-40-%D9%88%D9%84%D8%AA-SS14/) Quantity: 3, Prefer: 10, Supplier: RoboEQ
- [ ] [**LED_0805_Red**](https://lionelectronic.ir/products/2207-XL-2012SURC) Quantity: 1, Prefer: 10, Supplier: LionElectronic  
- [ ] [**LED_0805_Blue**](https://lionelectronic.ir/products/3268-XL-2012UBC) Quantity: 2, Prefer: 10, Supplier: LionElectronic  
- [ ] [**LED_0805_Yellow**](https://lionelectronic.ir/products/3267-XL-2012UYC) Quantity: 1, Prefer: 10, Supplier: LionElectronic  
- [ ] [**LED_0805_Green**](https://lionelectronic.ir/products/3265-XL-2012SYGC) Quantity: 4, Prefer: 10, Supplier: LionElectronic

## Switch
- [ ] [**SW_Relay**](https://roboeq.ir/products/detail/0308060/%D8%B1%D9%84%D9%87-12-%D9%88%D9%84%D8%AA-%D8%AA%DA%A9-%DA%A9%D9%86%D8%AA%D8%A7%DA%A9%D8%AA-10-%D8%A2%D9%85%D9%BE%D8%B1-5-%D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) Quantity: 3, Prefer: 5, Supplier: RoboEQ
- [ ] [**SW_PushButton-6-3.7-2.5**](https://lionelectronic.ir/products/4165-TS365TP) Quantity: 2, Prefer: 10, Supplier: LionElectronic

# 🌟 Support Me
If you found this repository useful:
- Subscribe to my [YouTube Channel](https://www.youtube.com/@aKaReZa75).
- Share this repository with others.
- Give this repository and my other repositories a star.
- Follow my [GitHub account](https://github.com/aKaReZa75).

# ✉️ Contact Me
Feel free to reach out to me through any of the following platforms:
- 📧 [Email: aKaReZa75@gmail.com](mailto:aKaReZa75@gmail.com)
- 🎥 [YouTube: @aKaReZa75](https://www.youtube.com/@aKaReZa75)
- 💼 [LinkedIn: @akareza75](https://www.linkedin.com/in/akareza75)

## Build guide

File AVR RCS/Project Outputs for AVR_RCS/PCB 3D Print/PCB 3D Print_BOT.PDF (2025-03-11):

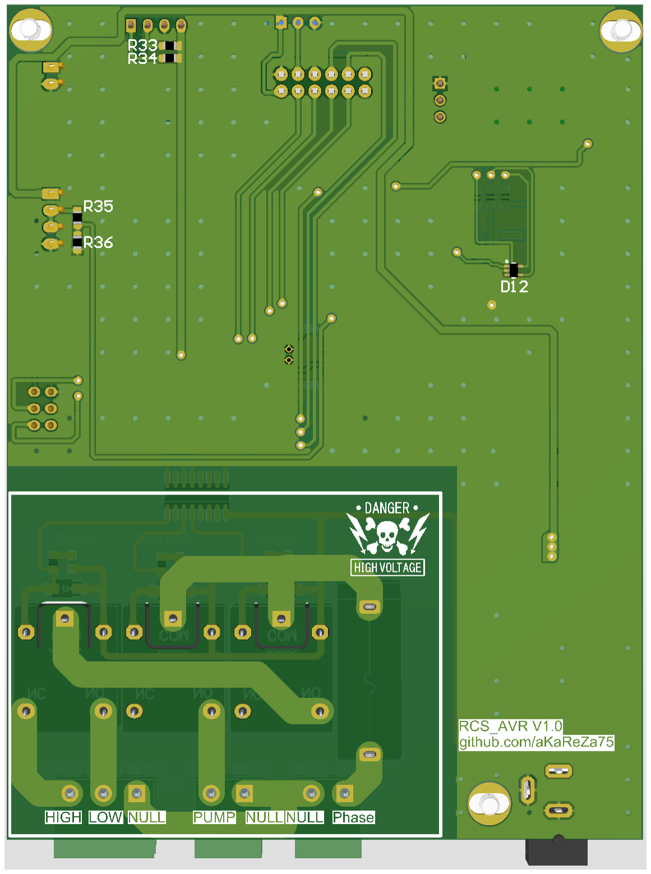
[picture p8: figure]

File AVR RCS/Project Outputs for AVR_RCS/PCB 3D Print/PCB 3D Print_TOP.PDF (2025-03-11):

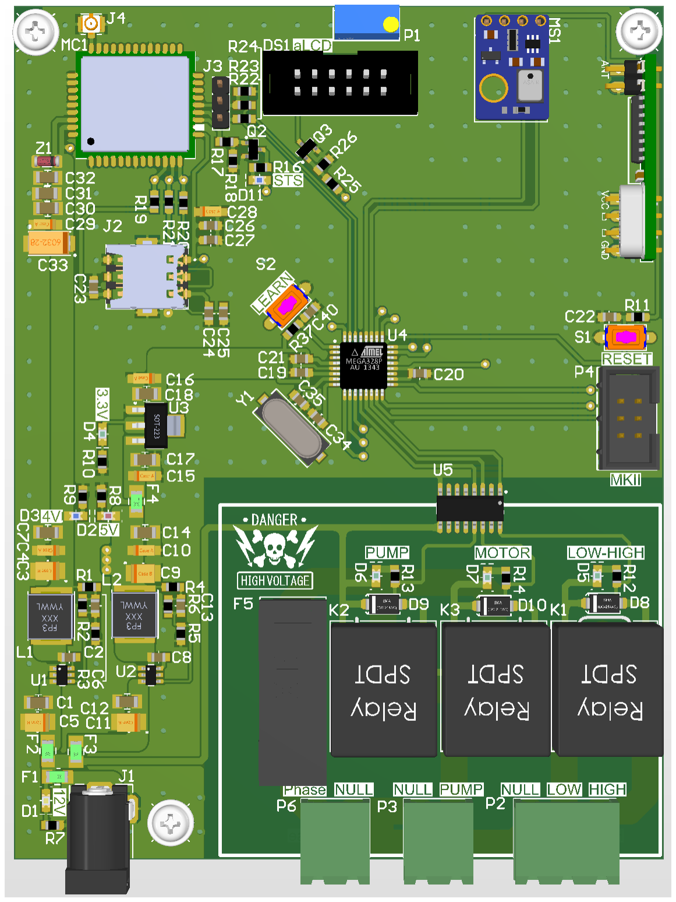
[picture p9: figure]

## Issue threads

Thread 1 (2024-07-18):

chila_pcb.intlib

JamilAhmadiRovari, 2024-07-18:
سلام و عرض ادب خدمت شما دوست گرامی
تسلیت ما رو بخاطر  وفات دوست گرامیتان پذیرا باشید و برای شما و خانواده آن مرحوم صبر جمیل را از خداوند متعال خواستاریم
دوست گرامی
متاسفانه در GitHub  کتابخانه مربوطه رو بصورت intlib و یکپارچه  پیدا نکردم و به شخصه دارم بصورت pcb و شماتیک استفاده میکنم که مزایای خودش رو داره اگه لینک مربوطه رو برای دانلود بزارید ممنون میشم

aKaReZa75, 2024-07-18:
سلام و عرض ادب، ممنونم از محبت و بزرگی و مهربانی شما.
فایلی که عرض کردم توی ویدئوی بعدی اضافه میکنم، اما اگه نیاز به اون قطعات دارید کتابخانه کامل رو میتونید از طریق لینک زیر دانلود کنید:
https://www.mediafire.com/file/jqd9kgzzjb5zkfy/Chila_PCB.IntLib/file

omid402, 2024-07-18:
با سلام عرض تسلیت خدمت شما دوست گرامی
خواستم چند نکته درباره طراحی قسمت تغذیه با توجه به تجربه خودم در مورد کار با GSM ها بگم
ماژول های gsm بسیار نسبت به تغذیه حساس هستند و رگولاتور سویچینگ برای آنها مناسب نیستند بهترین انتخاب رگولاتر خطی MIC29302 هست
با توجه به بلوک های که در طرح مفهومی ارائه کردین شما نیازی به ولتاژ 3.3 ولت و 5 ولت ندارید LCD کاراکتری ماژول گیرنده ریموت و آسی AVR با ولتاژ 4 ولت کار میکنه

Closed 2024-07-22.

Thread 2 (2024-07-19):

Power design

omid402, 2024-07-19:
با سلام و عرض تسلیت خدمت شما دوست گرامی
خواستم چند نکته درباره طراحی قسمت تغذیه با توجه به تجربه خودم در مورد کار با GSM ها بگم
1-ماژول های gsm بسیار نسبت به تغذیه حساس هستند و رگولاتور سویچینگ برای آنها مناسب نیست بهترین انتخاب رگولاتر خطی MIC29302 هست
2-با توجه به بلوک های که در طرح مفهومی ارائه کردین شما نیازی به ولتاژ 3.3 ولت و 5 ولت ندارید LCD کاراکتری , ماژول گیرنده  ریموت و آسی AVR با ولتاژ 4 ولت کار میکنه

tajmirik, 2024-07-19:
از لحاظ تامین جریان به مشکل نمیخوریم اگر برای همه از mic29302 استفاده کنیم ؟
مگر این که دو یا سه تا از همین رگولاتور بذاریم

tajmirik, 2024-07-19:
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

omid402, 2024-07-19:
این رگولاتور MIC29302 تا 3 آمپر جریان دهی داره و پیشنهاد شده در کاتالوگ GSM   هم هست من از این رگولاتور استفاده کردم و از خروجی 4.1 ولت برای SIM800C  ATMAGA64, LCD2*16, LM386 و ماژول گیرنده FSK استفاده کردم  کاملا OK بود و تعداد زیادی از این برد تولید کردم هیچ مشکلی نداشته

aKaReZa75, 2024-07-19:
> با سلام و عرض تسلیت خدمت شما دوست گرامی
>
سلام و عرض ادب، بسیار ممنونم از لطف شما، انشالله همیشه سلامت باشید.

> خواستم چند نکته درباره طراحی قسمت تغذیه با توجه به تجربه خودم در مورد کار با GSM ها
>
ممنونم از لطف شما

> 1-ماژول های gsm بسیار نسبت به تغذیه حساس هستند و رگولاتور سویچینگ برای آنها مناسب نیست بهترین انتخاب رگولاتر خطی MIC29302 هست
>
بله کاملا همینطوره، اما بستگی داره از چه رگولاتوری با چه فرکانس و همینطور از چه فیلتری برای اون استفاده کرده باشید، اما کاملا موافقم با شما که رگولاتور های خطی خیلی خیلی در خصوص مباحث نویز و ... کم درده سر تر هستند و پیشنهاد خوبی هست که از رگولاتور خطی استفاده کنیم.

> 2-با توجه به بلوک های که در طرح مفهومی ارائه کردین شما نیازی به ولتاژ 3.3 ولت و 5 ولت ندارید LCD کاراکتری , ماژول گیرنده ریموت و آسی AVR با ولتاژ 4 ولت کار میکنه
>
بله کاملا درست میفرمایید و میشه رگولاتورهایی که فرمودید رو حذف کرد، اما باید با دید اینکه این پروژه اموزشی هست نگاه کرد و هدف یادگرفتن بیشتر هست و ملاحظاتی که برای یک محصول تجاری هست بسیار متفاوت هست بایک پروژه آموزشی.
مورد دوم هم این هست که این برد قراره برای سایر میکروکنترلرهای دیگه غیر از AVR هم استفاده بشه و درسته که شروعش با AVR هست که میتونه رنج تغذیه 3.3 تا 5 ولت رو داشته باشه، اما میکروکنترلرهای دیگه ای که با اونها کار میکنیم اینطوری نیستند و همگی 3.3 ولت هستند، اگه از اول این بخش رو طراحی کنیم، برای بقیه میکروکنترلرها کار ما ساده تر میشه و نیازی به تغییر بلوک تغذیه نیست.

 ممنونم از توجهتون و نکاتی که فرمودید.

Closed 2024-07-25.

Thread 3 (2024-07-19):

Power Supply

mehrdadqasemitaj, 2024-07-19:
سلام جناب مهندس. تسلیت میگم روحشون شاد و نامشون جاودان . چندتا پیشنهاد داشتم برای طراحی 1-وجود چند پوش باتن و یا کی پد برای تنظیم کردن سنسور های دما و رطوبت و وجود بازر برای هشدار علاوه بر اس ام اس . 2- اس ام اس و آلارم در صورت قطعی برق .3- در نمونه پیشرفته تر میتونه گرفتن فیدبک هایی از وضعیت کولر باشه مثلا موتور و یا پمپ به درستی کار میکنند یا خیر .
برای قسمت تغذیه دوازده ولت آیا میشه به جای استفاده از آداپتور قاب دار از منبع تغذیه که به صورت pcb هست(بدون قاب ) استفاده کنیم و داخل باکس کنار مین برد ببندیم که البته میتونه باعث نویز بشه رو برد اصلی اما با راه کار هایی مثل شیلد کردن منبع این اثر رو کم کنیم .
برای قسمت tps54302 اول پیشنهاد ام رو میگم و بعد محاسبات .طبق تجربه دوستان و نه خودم استفاده از خازن تانتالیوم 6.3 و حتی 10 ولت در مدارات با ولتاژ 5 ولت باعث سوختن خازن ها شده بود و همچین برد توسعه ایی که خود تگزاس گذاشته داخل سایتش از خازن های مولتی لایر استفاده کرده.
محاسبات برای خروجی پنج ولت :
R2 = 100 k
R1 = 13.7 K
L = 8.1 UH = 10 uH / 3.5A
COUT = 56 uF / 10V
Cff = 87 pF = 100 pF
_ البته داخل دیتاشیت برای خروجی پنج ولت دو عدد خازن 22 میکرو فاراد پیشنهاد داده .
_ برای خرید مقاومت 13.7 کیلو هم فروشگاه "کاالکترونیک" در سایز 805 و 1206 موجوده . لینکش رو میزارم
https://kaelectronic.ir/index.php?route=product/product&product_id=6845
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

aKaReZa75, 2024-07-19:
> سلام جناب مهندس. تسلیت میگم روحشون شاد و نامشون جاودان
>
سلام و عرض ادب، بسیار ممنونم از لطف شما، انشالله همیشه سلامت و پایدار باشید.

> چندتا پیشنهاد داشتم برای طراحی
>
ممنونم از پیشنهاد هاتون، باهم همرو بررسی میکنیم:

> 1-وجود چند پوش باتن و یا کی پد برای تنظیم کردن سنسور های دما و رطوبت و وجود بازر برای هشدار علاوه بر اس ام اس
>
در خصوص قرار دادن پوشباتن مسئله ای ازین بابت نیست ( که پوش باتن رو اضافه کنیم)، شاید بهترش این باشه با خود اس ام اس دادن تعیین کنیم این حدود رو، به نظرتون این کار بهتر نیست؟ تا اینکه بریم پای دستگاه و روی پیشتبام و...
کلید رو قرار میدیم اما پیشنهاد خودم استفاده از کلید برای تعریف و تغییر ریموت ها هست.
در خصوص بازر هم میشه اضافه کرد اما مسئله اینجاست که دستگاه کنار کولر نصب میشه و ما دسترسی راحتی به اون نداریم، آیا باز به نظرتون میتونه کارآمد باشه؟

> 2- اس ام اس و آلارم در صورت قطعی برق
>
بسیار پیشنها خوب و کاربردی هست اما مسئله ای که داره این هست که باید برای اون باتری نصب کنیم تا بتونه اس ام اس رو بفرسته، و اضافه کردن باتری یعنی باید مدار شارژ اون رو هم اضافه کنیم، اما خوب خیلی هم کار سختی نیست، میتونیم نظر بقیه دوستان رو هم بپرسیم.

> 3- در نمونه پیشرفته تر میتونه گرفتن فیدبک هایی از وضعیت کولر باشه مثلا موتور و یا پمپ به درستی کار میکنند یا خیر .
>
این کارو هم میشه با اضافه کردن سنسور جریان و وارد کردن مشخصات کولر ( حدود جریان کاری پمپ، دور کند و دور تند ) انجام دادم اما حجم مدار زیاد میشه ولی خب شدنی هست.

> برای قسمت تغذیه دوازده ولت آیا میشه به جای استفاده از آداپتور قاب دار از منبع تغذیه که به صورت pcb هست(بدون قاب ) استفاده کنیم و داخل باکس کنار مین برد ببندیم که البته میتونه باعث نویز بشه رو برد اصلی اما با راه کار هایی مثل شیلد کردن منبع این اثر رو کم کنیم .
>
بله حتما میشه این کارو کرد ولی راه کم درده سرتر رو انتخاب کردم، ولی خیلی دستگاه جمع و جور تر میشه اگه آداپتور خارجی حذف بشه و تغذیه داخل خود دستگاه قرار بگیره.این مورد رو شاید بشه آخر کار پیاده کرد، ببینیم فضای کافی داریم داخل جعبه یا خیر.

> برای قسمت tps54302 اول پیشنهاد ام رو میگم و بعد محاسبات .طبق تجربه دوستان و نه خودم استفاده از خازن تانتالیوم 6.3 و حتی 10 ولت در مدارات با ولتاژ 5 ولت باعث سوختن خازن ها شده بود و همچین برد توسعه ایی که خود تگزاس گذاشته داخل سایتش از خازن های مولتی لایر استفاده کرده.
>
خازن های تانتال به صورت کلی خیلی به ولتاژ حساس هستند و نباید اضافه ولتاژ داشته باشند، این شرایطی که میفرمایید حتما خود 5 ولت صاف نبوده و ریپل و اسپایک های زیادی داشته وگرنه خازن 10 ولت برای ولتاژ 5 ولت آسیب نباید ببینه، من خودم همیشه از 6.3 استفاده کردم برای 5 ولت و اوکی بوده.
مزیت اصلی تانتال ها نسبت به مولتی لایرها ESR پایین اونها هست و انتخاب بهتری هست اما هزینه کار رو بالا میبره، عموما توی کاربرد های تجاری این موضوع خیلی مهمه، ولی برای برد ما هزینه نهایی پروژه خیلی مهم نیست، چون یک محصول تجاری نیست و هدفش آموزش هست پس قیمت اگه بیشتر هم بشه مسئله ای نداره.

> محاسبات برای خروجی پنج ولت :
R2 = 100 k
R1 = 13.7 K
L = 8.1 UH = 10 uH / 3.5A
COUT = 56 uF / 10V
Cff = 87 pF = 100 pF
_ البته داخل دیتاشیت برای خروجی پنج ولت دو عدد خازن 22 میکرو فاراد پیشنهاد داده .
>
ممنونم از محاسبه ای که زحمت کشیدین و انجام دادین ولی من هنوز محاسبه نکردم، هرموقع انجام دادم مقایسه میکنیم محاسبتمون رو باهم.

>  برای خرید مقاومت 13.7 کیلو هم فروشگاه "کاالکترونیک" در سایز 805 و 1206 موجوده . لینکش رو میزارم
https://kaelectronic.ir/index.php?route=product/product&product_id=6845
>
ممنونم از لطف شما، صفحه خرید قطعات رو ویرایش میکنم و لینک شمارو اضافه میکنم.

از لطف شما ممنونم حسابی زحمت افتادید.

mehrdadqasemitaj, 2024-07-22:
تمام نکاتی که گفتید منطقی بود و من یک جاهایی از پروژه رو اشتباه متوجه شده بودم و فک میکردم قراره دستگاه داخل خونه نصب شه نه روی پشتبام . مرسی از راهنمایی و نکات خوبتون

Closed 2024-07-25.

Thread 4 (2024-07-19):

LED Resistor

mehrdadqasemitaj, 2024-07-19:
مقادیر مقاومت برای ال ای دی ها :
LED Green (3V3) : 90 ohm => 100 ohm
LED Blue (4V) : 100 ohm
LED Red (5V) : 260 ohm => 330 ohm
LED Yellow (12V) : 960 ohm=>  1Kohm
_اعداد اول اعداد محاسبه شده و اعداد جلوی آنها استاندارد موجود مقاومت هاست .
مدار عملی هم برای تست شدت نور اونها بستم اما ال ای دی 0805 آبی نداشتم به جای آن 0603 گذاشتم که فک میکنم با اینکه سایز کوچک تری نسبت به سایر ال ای دی ها داره اما پرتاب نور بیشتری داره و شایدم بخاطر ماهیت نور ال ای دی آبی است .
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

aKaReZa75, 2024-07-19:
سلام و عرض ادب، بسیار ممنونم از زحمتی که کشیدید، بنده هنوز محاسبه نکردم ولی قطعا همرو درست حساب کردید.
بسیارهم لذت بردم از کارتون، خیلی عالی هست که همه چیو عملی تست میکنید.
موفق باشید.

Closed 2024-07-22.

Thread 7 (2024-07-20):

تامین ولتاژ موزد نیاز ماژول GSM توسط دیود 1N4007

hamidtb, 2024-07-20:
سلام، روزتون بخیر
نظرتون در باره تامین ولتاژ مورد نیاز ماژول GSM  توسط یک عدد دیود 1N4007 چی هست؟
به این صورت که ولتاژ 5 ولت توسط رگولاتور تامین بشه و توسط دراپ اوت دیود 1N4007 (حدود 0.7V) ولتاژ تقریبی 4.3 ولت برای ماژول ساخته بشه؟

aKaReZa75, 2024-07-20:
سلام و عرض ادب.
خیر، به هیچ عنوان این موضوع پیشنهاد نمیشه، علتشم اینهکه ماژول های GSM بسیار حساس به تغذیه هستند و باید تغذیه اونها رگوله بشه و یک ولتاژ صاف، بدون نویز و ریپل به این ماژولها داده بشه تا عملکرد پایداری رو داشته باشند که این موضوع با دیود ممکن نیست.

hamidtb, 2024-07-21:
سلام مجدد
امکان این که به جای 5 ولت ولتاژ 4.2 ولت از رگولاتور خروجی گرفته بشه و هم برای ماژول gsm و هم برای سایر قطعاتی که به 5 ولت نیاز دارن استفاده بشه وجود داره؟

aKaReZa75, 2024-07-21:
> سلام مجدد امکان این که به جای 5 ولت ولتاژ 4.2 ولت از رگولاتور خروجی گرفته بشه و هم برای ماژول gsm و هم برای سایر قطعاتی که به 5 ولت نیاز دارن استفاده بشه وجود داره؟
>
سلام و عرض ادب، این موضوع توی https://github.com/aKaReZa75/RCS_AVR/issues/2#issuecomment-2239743138 این قسمت بحث شده در موردش، اما به صورت خلاصه بپم، بله میشه ولی یک اگر و اما داره.

Closed 2024-07-22.

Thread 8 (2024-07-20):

استفاده از رگولاتور های جدید

hamidtb, 2024-07-20:
سلام، روزتون بخیر
نظرتون درباره استفاده از رگولاتور های جدید تر به جای AMS1117 چی هست
با توجه به این که با سوختن این رگولاتور، ورودی به خروجی متصل میشه و برای مدار بعد از رگولاتور خطرناک هست

رگولاتور هایی نظیر [TLV74333PDBVR](https://lionelectronic.ir/products/2492-TLV74333PDBVR)
[AP2125K-3.3TRG1](https://lionelectronic.ir/products/2713-AP2125K-3.3TRG1)
[ME6210A33PG](https://lionelectronic.ir/products/2834-ME6210A33PG)

aKaReZa75, 2024-07-20:
سلام و عرض ادب، بله چرا که نه، استقبال هم میکنیم.
شما میتونید پروژه رو Fork بگیرید، تغییرات مد نظرتون رو اعمال کنید و به صورت Pull request برای بنده ارسال کنید تا توی پارت بعدی ویدئو بررسی کنیم.

Closed 2024-07-22.

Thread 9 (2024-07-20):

استفاده از TI Webench Power Designer - Texas Instruments

hamidtb, 2024-07-20:
سلام، روزتون بخیر
پیشنهاد میکنم جهت انتخاب و طراحی مدار رگولاتور از [TI Webench Power Designer - Texas Instruments](https://webench.ti.com/power-designer/switching-regulator) استفاده کنید
ممنونم

aKaReZa75, 2024-07-20:
سلام و عرض ادب، ممنونم از شما، توی ویدئو این لینکی که شما زحمت کشیدین رو معرفی میکنم.
موفق باشید.

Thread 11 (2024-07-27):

AVR Pins

HamidRezaKarimiS, 2024-07-27:
سلام
با توجه به محدود بودن Pin های میکرو، پیشنهاد میکنم پایه هایی که لازم داریم رو ابتدا مشخص کنیم تا در ادامه کمتر مشکل ایجاد بشه.
من پایه های کریستال خارجی رو در صفحه controller تخصیص دادم و pull کردم.

اگر صلاح میدونید، نوع ارتباط LCD، GSM و حتی ماژول ریموت هم مشخص کنید.

HamidRezaKarimiS, 2024-07-27:
سلام
برای جذاب تر شدن پروژه پیشنهاد میکنم.
پایه ماژول ریموت به int0 متصل بشه
نمایشگر با i2C متصل بشه و ماژول GSM( اگر از 800L استفاده میشه) با uart نرم افزاری به میکرو متصل بشه و uart اصلی با usbtottl به یه کامپیوتر برای debug متصل بشه.

aKaReZa75, 2024-07-28:
سلام و عرض ادب خدم شما دوست عزیز، بله موافقم با شما، ولی به احتمال زیاد از کریستال خارجی استفاده نکنیم، به نظرم پایه های IO کافی هستند تا ال سی دی رو به صورت موازی راه اندازی کنیم.
چونکه خد ال سی دی رو داریم از همون میشه به عنوان دیباگ استفاده کرد و درده سر UART نرم افزاری رو نداشته باشیم.
در خصوص اینکه گفتین Pull فرستادین، احتمالا اشتباهی شده، یکبار دیگه مرور کنید چونکه ریکوئست سمت من نیامده.
ممنونم از اینکه نظر خودتون رو بیان کردید.

HamidRezaKarimiS, 2024-07-29:
> در خصوص اینکه گفتین Pull فرستادین، احتمالا اشتباهی شده، یکبار دیگه مرور کنید چونکه ریکوئست سمت من نیامده. ممنونم از اینکه نظر خودتون رو بیان کردید.

آره ظاهرا بلد نیستم، هر کاری کردم که نشد. ادامه میدم تا بشه.

Closed 2024-08-23.

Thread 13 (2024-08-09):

TPS54302 SIMULATION IN ORCAD CADENCE

JamilAhmadiRovari, 2024-08-09:
سلام و عرض ادب خدمت استاد گرامی
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
محاسبه قطعات و شبیه سازی مدار طبق ویدئو
**#**aKaReZa 72 - RCS, AVR  - PART C.mp4****
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
محاسبه قطعات و شبیه سازی مدار با خازن فیدبک 120pF و مقاومت 13.7 کیلو  مطابق با توضیحات ویدئو
**# **aKaReZa 65 - PCB, Switching Regulato.mp4****
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
محاسبه قطعات و شبیه سازی مدار با خازن فیدبک 120pF و مقاومت 13.6 کیلو  مطابق با توضیحات ویدئو
 ****aKaReZa 65 - PCB, Switching Regulato.mp4****

**************      **در انتظار ویدئوی بعدی**      ************************

aKaReZa75, 2024-08-23:
سلام و عرض ادب خدمت شما، بسیار ممنونم از محبت شما، بسیار کار با ارزشی رو انجام دادید، توی ویدئو بعدی بررسی میشه.

JamilAhmadiRovari, 2024-08-28:
سلام استاد گرامی
این ادرس ایمیل برای دسکتاپ اینجانب میباشد و متاسفانه سینک نیست و خیلی دیر
متوجه میشم
بابت دیر متوجه نشدن پیام های شما عذر بنده را پذیرا باشید
متشکرم

On Fri, Aug 23, 2024 at 11:31 AM Hossein Bagheri ***@***.***>
wrote:

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

Closed 2024-08-23.

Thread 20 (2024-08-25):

من با این محیط کنار نمیام استاد ،خواستم جواب سوال ویدیوی آخر رو بدم

omid-mazarei, 2024-08-25:
سلام استاد
 ویدیوی آخر هم واقعا عالی بود ولی من با این محیط هنوز نتونستم کنار بیام به هر حال اینجا جواب سوالی که مطرح کردین رو میزارم

به هر حال معذرت میخوام
البته میدونم مقدار ها دقیق نیست
ادیت:البته این مدار یه ایرادی هم داره اونم باز گذاری  اپتو کوپلر روی تقسیم مقاومتی است که فکر کنم یک آپ امپ یا کامپراتور نیاز باشه
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

ادیت شماره 2
فکر میکنم این بهتر باشه

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

البته اگه دقت و سرعت بیشتری بخواهیم یک LM311 را بجای فیلتر بعد از اپتو کوپلر و قبل از میکرو بذاریم چون احتمالا ابن خازنها تاخیر ایجاد می کنند

البته اشمیت تریگر هم احتمالا میشه گذاشت

aKaReZa75, 2024-09-07:
سلام و عرض ادب، ممنونم از شما، توی ویدئو مربوطه بررسی خواهد شد، موفق باشید.

omid-mazarei, 2024-10-04:
سلام  و عرض ادب استاد،ممنون از راهنمایی هاتون،ابتدا تشکر می کنم ازاینکه قابل دونستین  تحلیلی که روی این شماتیک انجام دادین ،فرمودین که احتمالا این بخش دیتکتور از پروژه حذف میشه ولی برای جنبه آموزشی خودم اینو میخواستم خدمتتون عرض کنم که اون دیود زنر رو بیشتر از اینکه برای محافظت از اپتو کوپلر بذارم برای این گذاشته بودم که خارن صافی کوچک بشه،استدلال  من هم این بود که با توجه به امپدانسی (مقاومت فرکانسی ،اگر اسم درستش باشه) که خازن سری ایجاد میکنه کلا جریان کوچکی خازن سری و قسمت دیتکتور اپتو کوپلر رد خواهد شد پس زنر هم می تونه این جریان کم رو تحمل کنه ومی تونه ولتاژ رو در حد همون 5 ولت نگه دارده پس ولتاژ دو سر خازن صافی c1 از ولتاژ زنر که 5 ولته بیشتر نخواهد شد پس یرای خازن صافی احتیاج به خازن ولتاژ بالا نخواهد بود و با یک خازن الکترولیتی 15 ولت مسئله حله،اینکه از یکسو ساز نیم موج هم استفاده کردم هم برا کم شدن" حجم مدار "بود و هم "خودش به کم شدن توان کمک میکنه" وگرنه از تمام موج استفاده می کردم، در باره مقاومت 330 اهم هم که فرمودین حتما کافیه چون همانطور که مشاهده میکنین کلا 10 میلی امپر برای روشن شدن ال ای دی اپتو کوپلر عبور میکنه که مطابق دیتا شیته،من اینو در پرتئوس شبیه سازی کردم و عمدا ولتاژ و جریان قسمت های مهم  رو هم با ولت متر و امپر متر پرتئوس اندازه گیری کردم که در  شماتیک است و اگر درست باشه خوب برای کار عملی احتیاج به این ولت متر و امپر مترها نیست البته در باره بقیه موارد از جمله مقدار مقاومت موازی با خازن و گذاشتن مقاومت 10 اهمی در نول و اون فسمت فیلتر بعد از اپتو کوپلر اطلاعات خوبی بمن داداه شد و از این بابت متشکرم،اون مدار دوستمون هم خوب بود ولی چند ایراد من دارم 1-برای یک همچین موردی که جریان زیادی نمی خواییم بنظر من همون یک عدد دیود و یکسو سازی نیم موج کافیه که برای یک دیتکتور که باید کوچک باشد بهتره،واون مقاومت 1 کیلو اهم هم که قبل از اپتو کوپلر گذاشتن با توجه به ولتاژ دو سر مقاومت و جریان عبوری باید اقلا 2 وات باشد که بزرگ است ،اینو هم تو شبیه ساز تست کردم حدودا .7 وات مصرف مقاومت قبل از اپتو کوپلره. لطفا جهت جنبه اموزشی ارشاد بفرمایید ممنون

aKaReZa75, 2024-10-04:
سلام . عرض ادب مجدد خدمت شما.
اول از هر چیزی میخوام یک اعتراف کنم و اونم این هست که من اصلا متوجه نشدم که اون دیود، دیود زنر هست! خیلی وقته با پروتئوس کار نمیکنم و نماد زنر توی پروتئوس  غیر متعارف هست، برای همین اصلا متوجه نشدم، اما قرار دادن زنر کار درستی هست و باعث میشه اون مشکل اضافه ولتاژی که بنده عرض کردم وجود نداشته باشه و حداقل اپتوکوپلر بخاطر ولتاژ بالا نسوزه!
در خصوص نیم موج بودن یا تمام موج بودن بنده کماکان نظرم بروی تمام موج هست، ولی این مدار شمارو هم تست میکنیم ( به صورت عملی)
در خصوص مقاومت 330 اهم، با توجه به اینکه من اصلا متوجه زنر نشده بودم، با وجود زنر، مقدار این مقاومت توجیح پذیر هست و حق با شماست.
در خصوص ولتاژ خازن صافی هم حق با شماست، با وجود زنر مقدار ولتاژ خازن خیلی کم میشه و حجمش کوچیک میشه به طبع.
دو نکته هم در خصوص شبیه سازیتون عرض کنم، اول اینکه زمین دو سمت اپتوکوپلر نباید یکی باشه، چونکه هدف ایزولاسیون هست، پس باید زمین ها حتما متفاوت باشند.
مورد دوم هم توی این نوع مدار های خیلی مهمه حالت گذرا هم تحلیل بشه که مدار توی زمانی که برای بار اول قراره متصل بشه، رفتارش و جریان اولیه به چه شکل هست که توی آموزش پارت دوم پروتئوس این موضوع رو دیدیم.
حالا چه این قسمت از مدار حذف بشه و چه نشه! در هر دو صورت خودموت به صورت عملی یک مدار مناسب برای این موضوع طراحی میکنیم چونکه خیلی کاربردی هست و قطعا از مدار پیشنهادی شما و ددوست عزیزه دیگمون کمک میگیرم و به یک مدار نهایی میرسیم.
بازم از شما هم ممنونم و هم عذر میخوام، موفق باشید.

Closed 2024-09-26.

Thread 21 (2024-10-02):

تغییر نحوه نصب و قرار گیری دستگاه

aKaReZa75, 2024-10-02:
سلام و عرض ادب، لطفا نظر خودتون رو در خصوص تغییر و نحوه نصب جعبه رو بفرمایید و حتی اگر پیشنهاد بهتری رو دارید همینجا بفرمایید:

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

توی این روش دیگه خود کلید کولر رو باز میکنیم و دستگاه رو بجای کلید کولر قبلی نصب میکنیم.

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

چونکه خود جعبه Wall-Mount هست خیلی راحت میشه جعبه رو به دیوار متصل کرد.

hisec1, 2024-10-04:
سلام استاد به نظرم اینجوری کار شکیل و بهتر در می یاد با پیشنهاد شما موافقم

Closed 2024-10-10.

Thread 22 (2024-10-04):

اپلیکیشن

hisec1, 2024-10-04:
با سلام و احترام
استاد اگه میشه یه اپ اندرویدی هم واسه دستگاه بسازیم و البته آموزش هم داده بشه خیلی خوب میشه

aKaReZa75, 2024-10-07:
سلام و عرض ادب، بله چشم توی ویدئو مربوط به دوره این موضوع رو مطرح میکنم.

tajmirik, 2024-10-23:
به نظرم خیلی ایده خوب و قشنگیه من که امیدوارم وقت کنید

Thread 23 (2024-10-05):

نصب کنار کلید

mm-mohammadi, 2024-10-05:
این نوع طراحی بسیار منطقی و بهینه بنظر میرسه

aKaReZa75, 2024-10-07:
سلام و عرض ادب، ممنونم از بیان نظرتون.
ایشیو مربوط به این موضوع در لینک زیر هست:
https://github.com/aKaReZa75/RCS_AVR/issues/21
موفق باشید.

Closed 2024-10-10.

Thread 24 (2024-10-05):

تغییر ای سی

mm-mohammadi, 2024-10-05:
سلام و عرض ادب ، ضمن تشکر از شما  اگر امکان داره از ای سی دیپ  استفاده کنید چرا که اکثر ما چند تایی از ان رو داریم و در ظمن تعویض این قطعه به هر دلیل به مراتب اسان تر و دردسترس تر خواهد بود.

aKaReZa75, 2024-10-07:
سلام و عرض ادب، بله چشم توی ویدئو بعدی این موضوع مطرح میشه، اگر کسی انجام دادم که چه عالی اونو کناب پروژه اصلی قرار میدم اگرم که نه خودم یه نسخه DIP رو هم میسازم و قرار میدم، اما بیس اصلی این پروژه و همه پروژه های بعدی SMD هست. موفق باشید

Closed 2024-10-10.

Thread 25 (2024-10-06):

ساخت کتابخانه یکپارچه از سایر کتابخانه ها

mm-mohammadi, 2024-10-06:
با عرض سلام و تشکر صمیمانه از آموزش های بسیار خوبتون لطفا یک ویدیو برای ساخت کتابخانه یکپارچه از سایر کتابخانه ها بطور مثال اضافه کردن یک قطعه از chilapcb به کتابخانه شخصی خودمان

aKaReZa75, 2024-10-07:
سلام و عرض ادب خدمت شما، بله ویدئو مربوط به ساخت کتابخانه التیوم رو پارت اولشو ساختم، و ادامه دار هم هست، این موضوعی که فرمودید روهم در نظر دارم که ریکورد کنم توی پارتهای بعدی، موفق باشید.

Closed 2024-10-10.

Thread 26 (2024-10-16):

چند مورد برای ویدئو بعدی

aKaReZa75, 2024-10-16:
1. قابلیت آپدیت ماژول GSM
2. مشکل سیم کارت و خازن C23
3.پلاریته خازنهای C5 - C11

aKaReZa75, 2025-05-11:
۴. برای اتصال نمایشگر ALCD، پیشنهاد می‌شود از کانکتور IDC نوع ۸×۲ استفاده شود؛ زیرا این مدل در بازار به‌راحتی قابل تهیه بوده و همچنین لحیم‌کاری آن نیز ساده‌تر و با کیفیت بهتری انجام می‌شود.

۵. برای ماژول ریموت کنترل کدلرن، در مراحل اولیه راه‌اندازی، استفاده از ماژول ASK مدل DX-RF 433 توصیه می‌شود؛ زیرا راه‌اندازی ساده‌تری دارد. در مراحل بعدی و برای بهبود عملکرد، این ماژول می‌تواند با مدل JMR RXB22 433MHz ASK جایگزین گردد.

۶. با توجه به تغییر در محل نصب پروژه، پیشنهاد می‌شود خروجی کانکتورهای فونیکس (Phoenix) به نوع چهار سیمه تغییر داده شود تا فرآیند نصب ساده‌تر و سریع‌تر انجام گیرد.

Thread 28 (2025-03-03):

مشارکت

hisec1, 2025-03-03:
با سلام و احترام
مهندس يک پيشنهاد داشتم در مورد برد RCS
اگه امکانش باشه بعد از اينکه نحوه ي خروجي از آلتيوم رو آموزش داديد و واسه چاپ بخواين بفرستيد ما حاضريم مشارکت کنيم و همراه با شما مونتاژ رو انجام بديم و حالا بعدش برنامه نويسي رو با شما پيش بريم
مشارکت براي خريد قطعات رو هم در خدمتيم
ارادتمند

aKaReZa75, 2025-03-04:
سلام و عرض ادب
خیلی ممنونم از پیشنهاد شما و اعلام آمادگیتون برای همکاری در پروژه پیش رو.
بله حتما مزاحمتون میشم، البته خرید های عمده اون انجام شده و فکر نمیکنم نیازی به خرید بیشتری باشه حالا موقع تهیه BOM بقیه موارد اون هم چک میشه.
در خصوص بحث مونتاژ چونکه مرحله مونتاژ و لحیم کاری و عیب یابی هم جزئی از بحث های آموزشی هست، مونتاژ رو خودم باید انجام بدم تا ویدئو اون تهیه بشه و توضیحات اونو رو بدم.
اما بازم ممنونم از پیشنهادی که دادید انشالله در پروژه های بعدی ازتون کمک میگیرم.
موفق باشید

Closed 2025-03-04.

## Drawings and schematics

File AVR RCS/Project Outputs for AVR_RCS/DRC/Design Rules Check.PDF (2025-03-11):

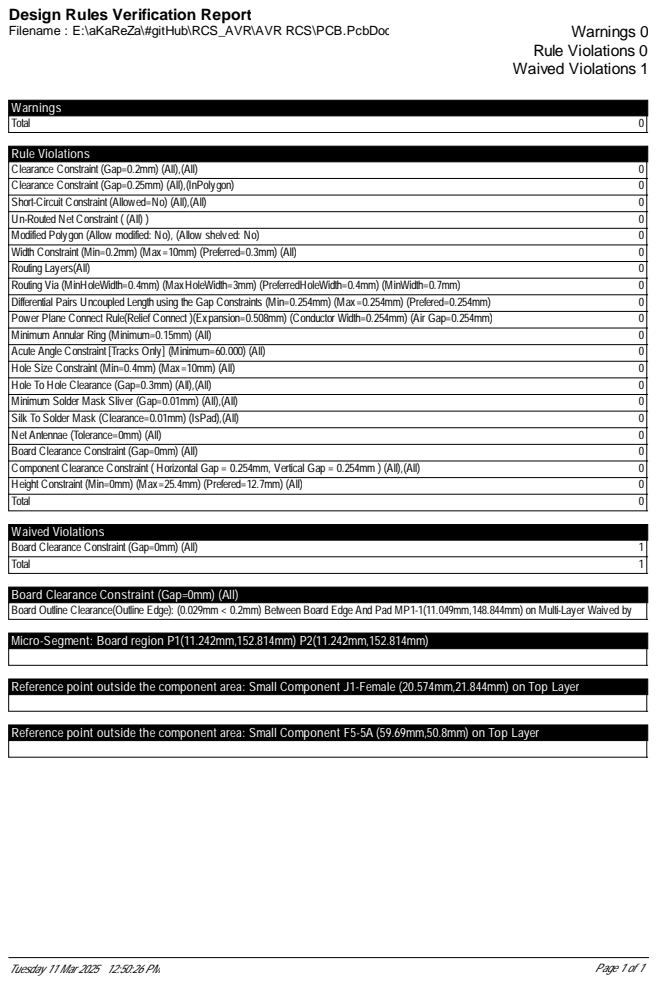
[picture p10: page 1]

Design Rules Verification Report

Board Clearance Constraint (Gap=0mm) (All)
Board Outline Clearance(Outline Edge): (0.029mm < 0.2mm) Between Board Edge And Pad MP1-1(11.049mm,148.844mm) on Multi-Layer Waived by

Micro-Segment: Board region P1(11.242mm,152.814mm) P2(11.242mm,152.814mm)

Reference point outside the component area: Small Component J1-Female (20.574mm,21.844mm) on Top Layer

Reference point outside the component area: Small Component F5-5A (59.69mm,50.8mm) on Top Layer

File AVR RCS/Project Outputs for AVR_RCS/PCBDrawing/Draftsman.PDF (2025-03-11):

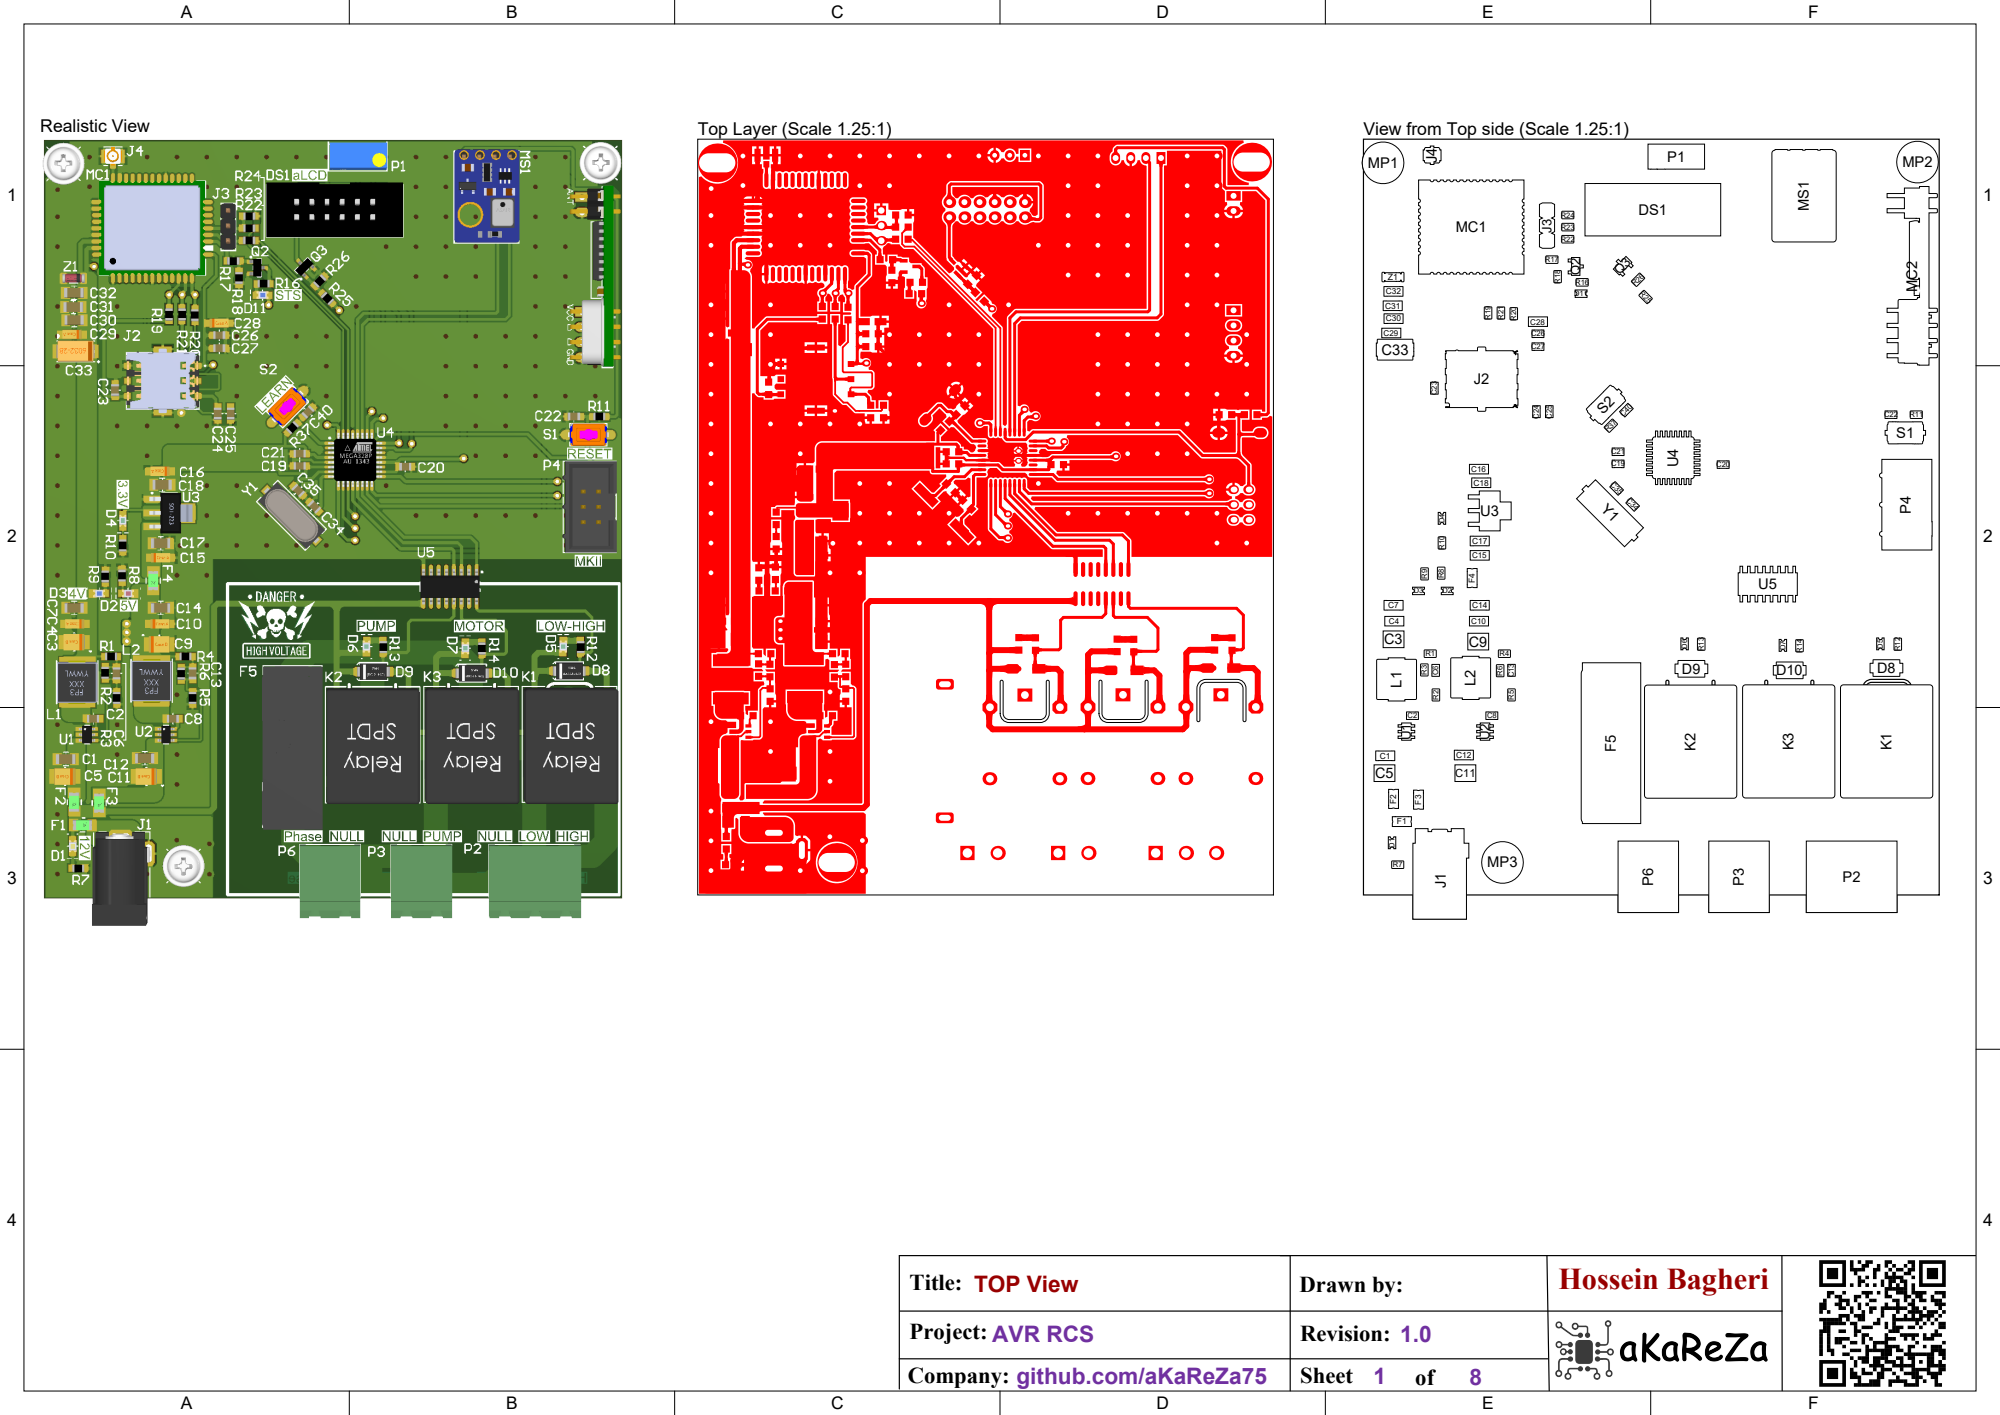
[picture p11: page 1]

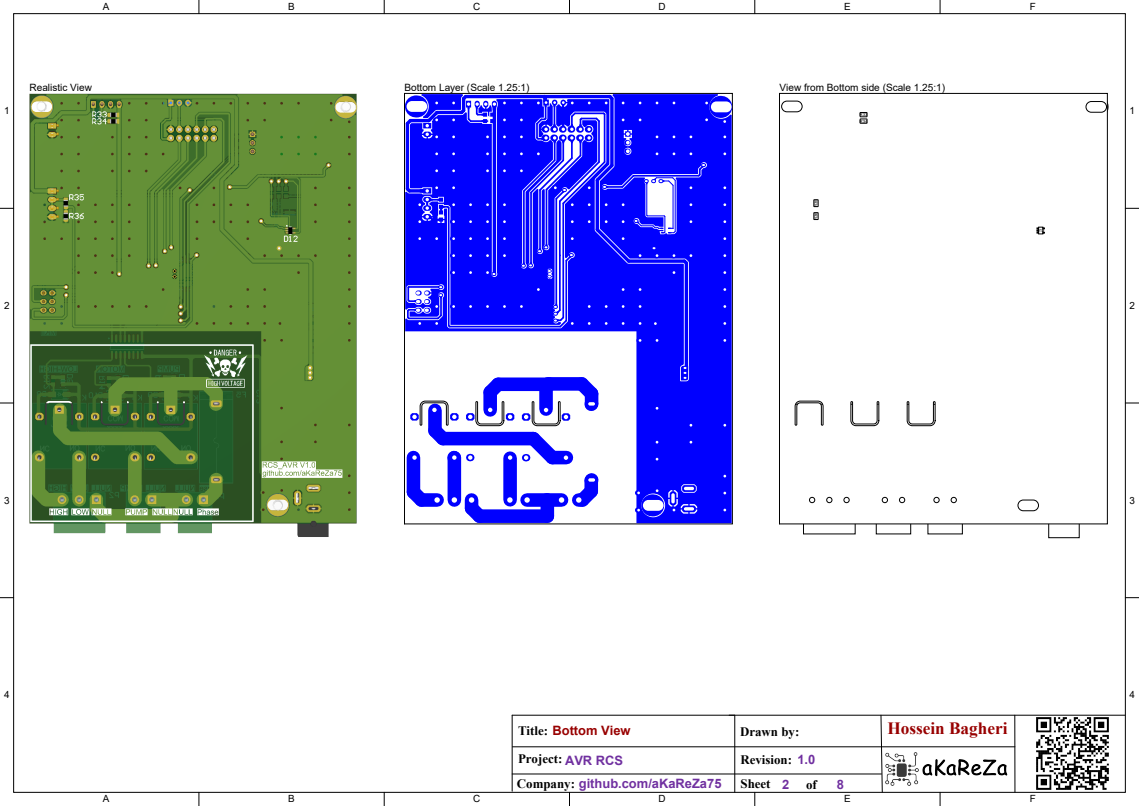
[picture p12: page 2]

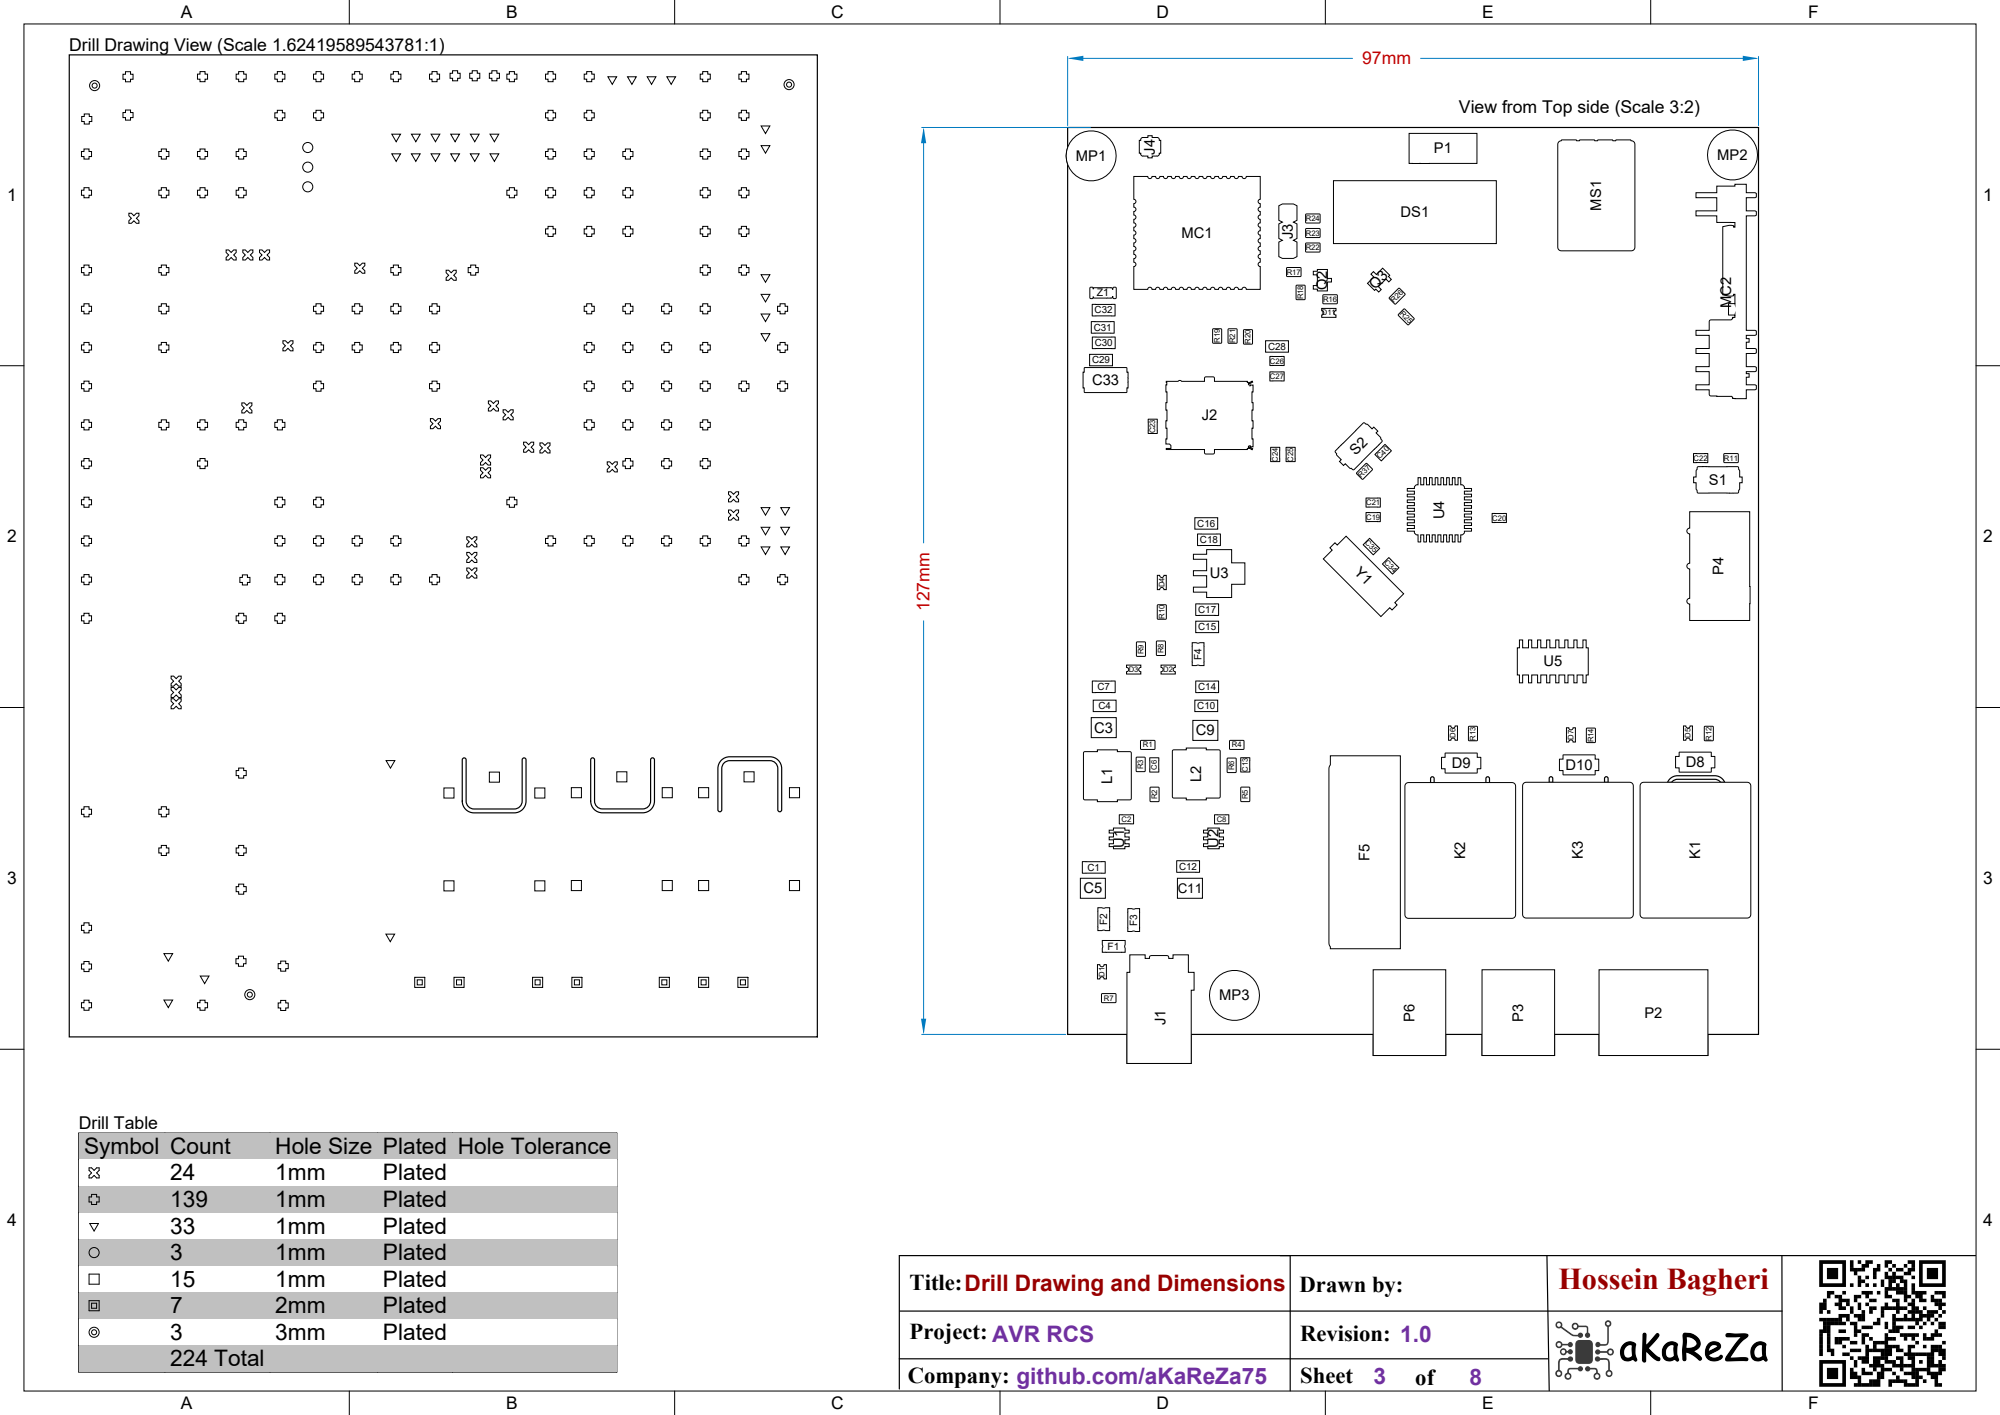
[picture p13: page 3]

Drill Drawing View (Scale 1.62419589543781:1)

View from Top side (Scale 3:2)

Symbol | Count | Hole Size | Plated | Hole Tolerance

24 | 1mm | Plated
139 | 1mm | Plated
33 | 1mm | Plated
3 | 1mm | Plated
15 | 1mm | Plated
7 | 2mm | Plated
3 | 3mm | Plated
224 Total

Title:
Drill Drawing and Dimensions

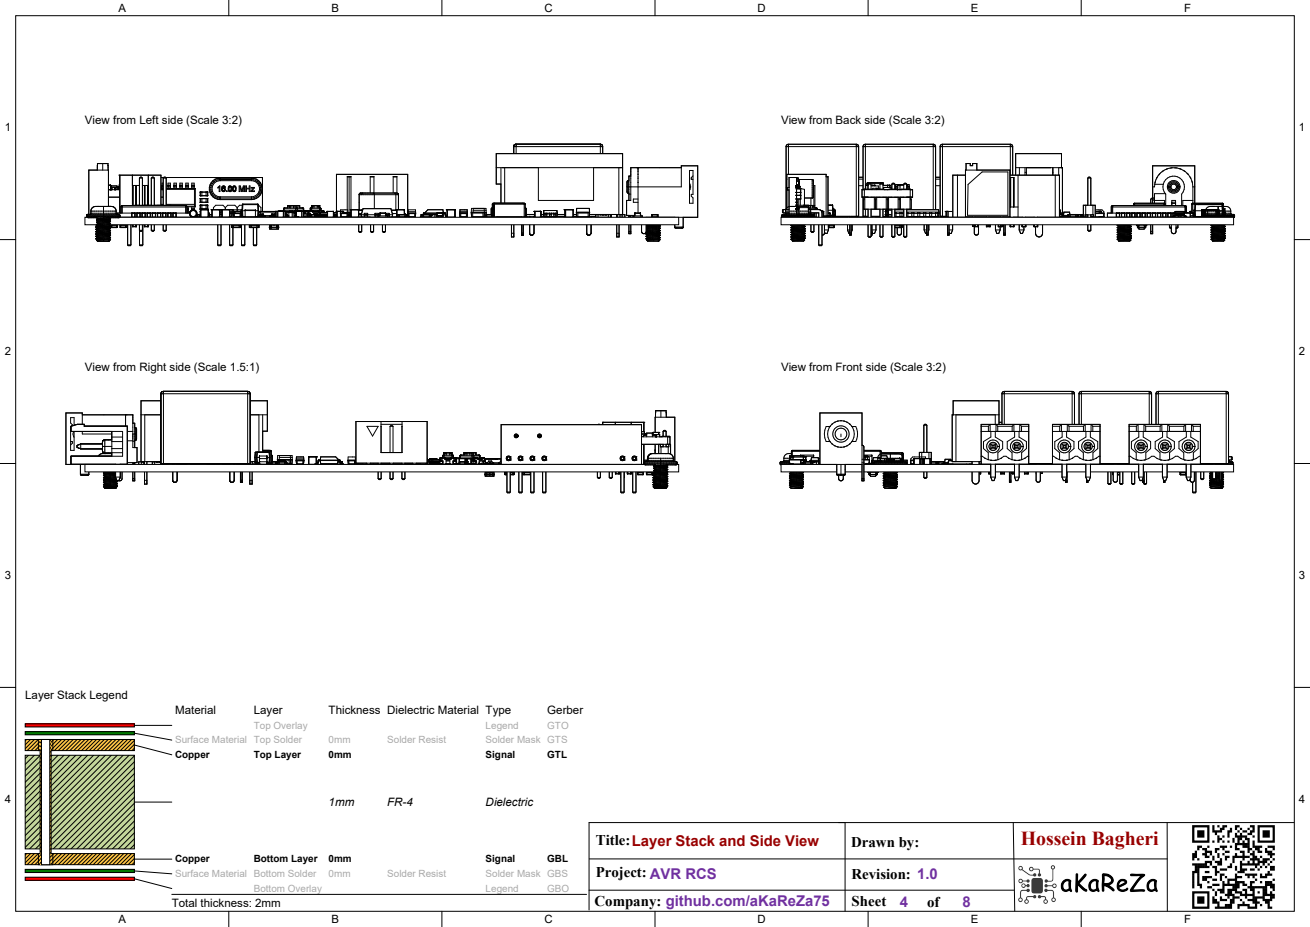
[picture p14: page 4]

View from Left side (Scale 3:2)

View from Back side (Scale 3:2)

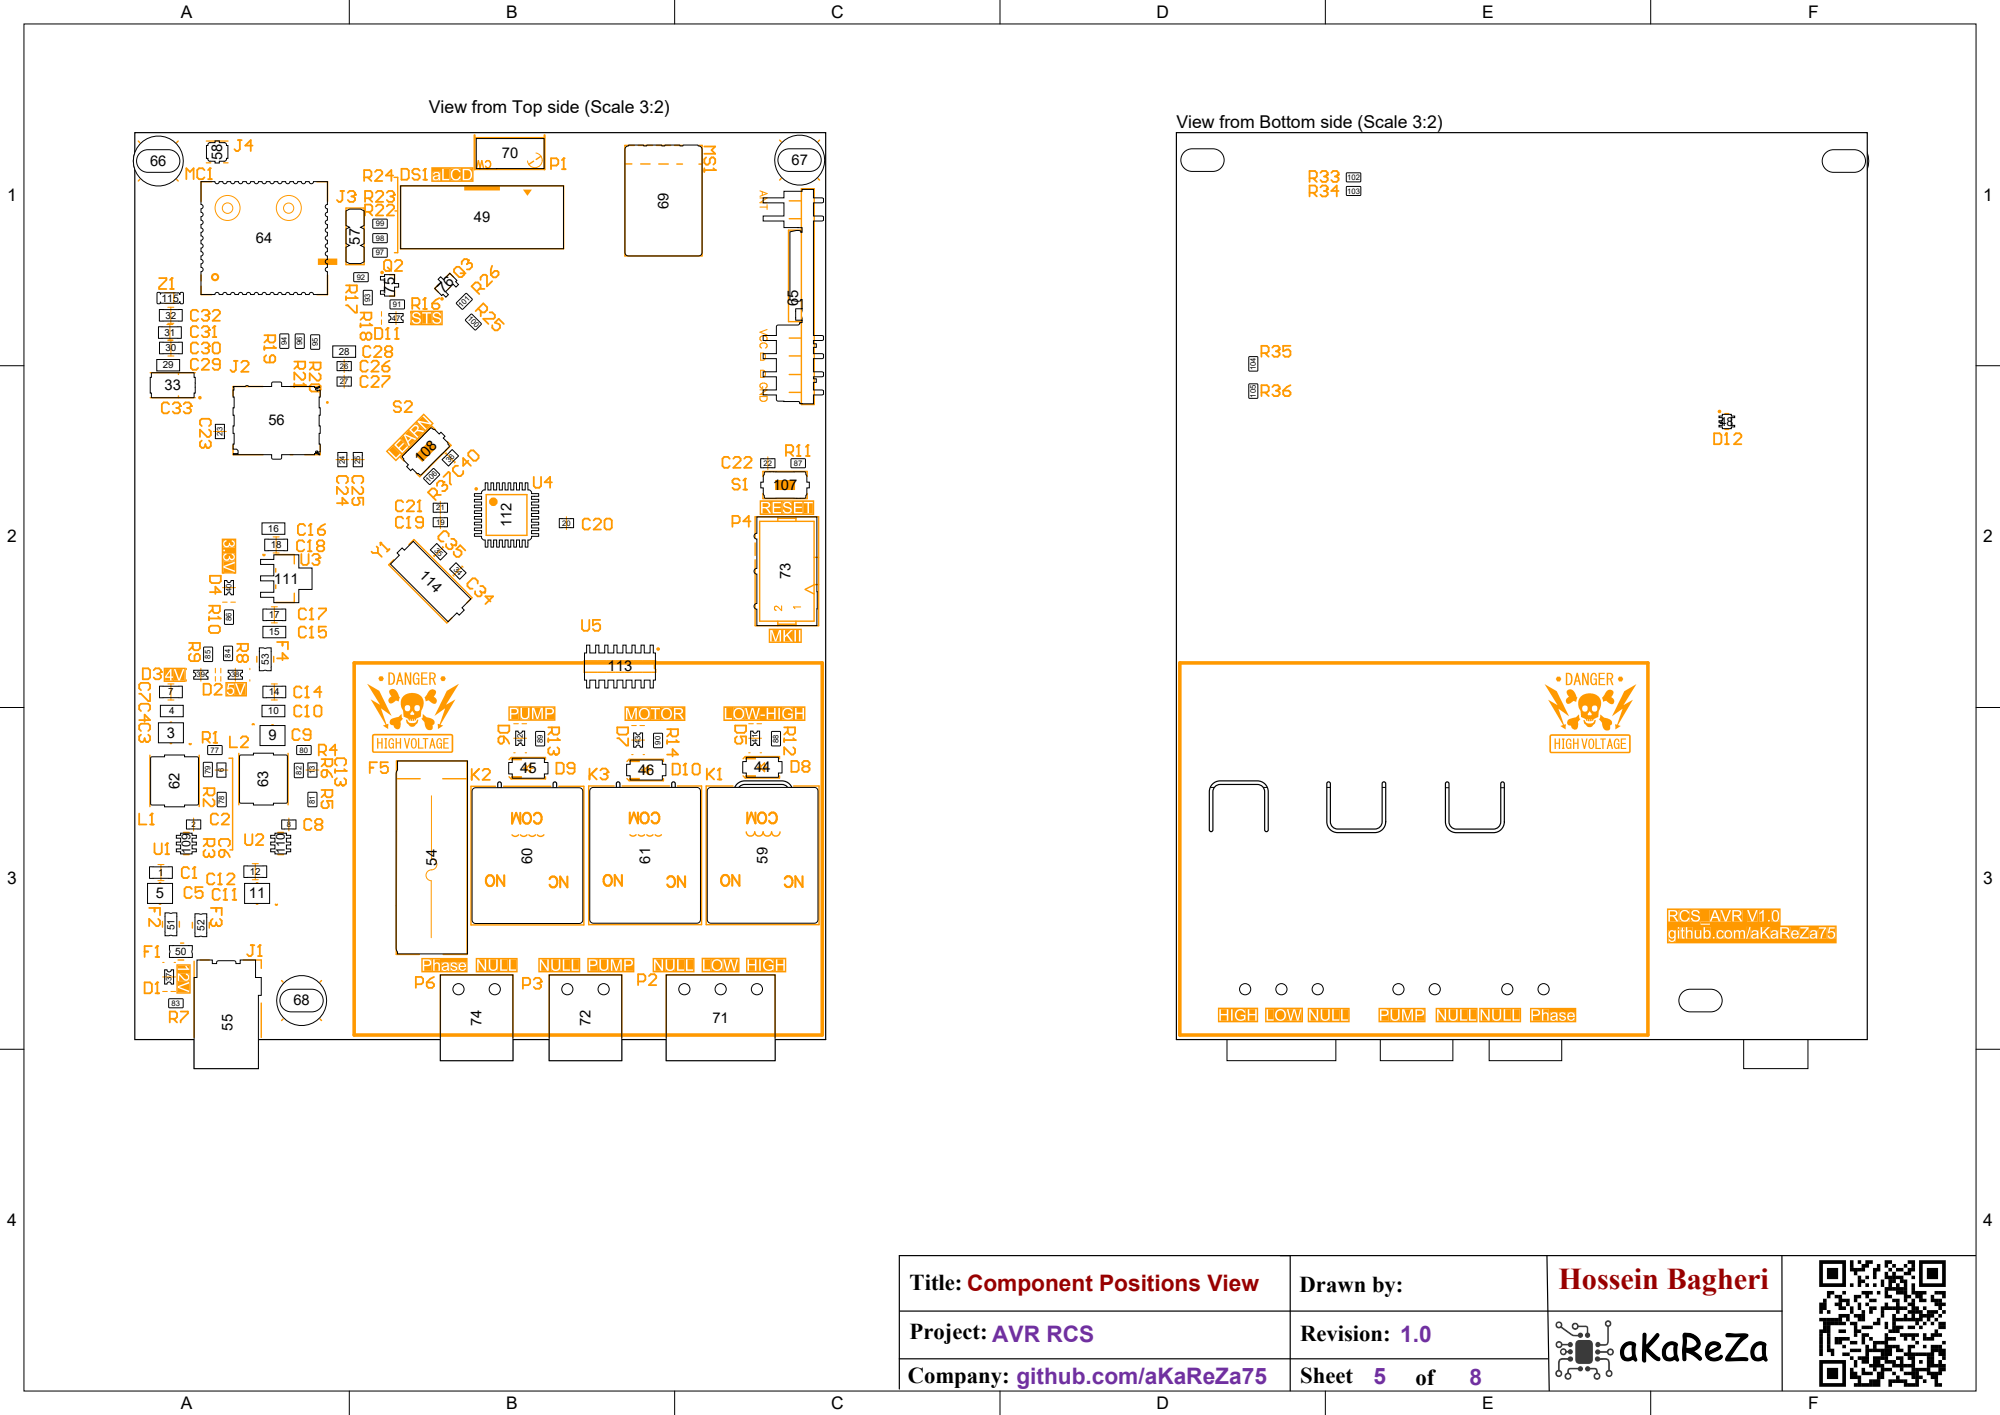
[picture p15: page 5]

View from Top side (Scale 3:2)

View from Bottom side (Scale 3:2)

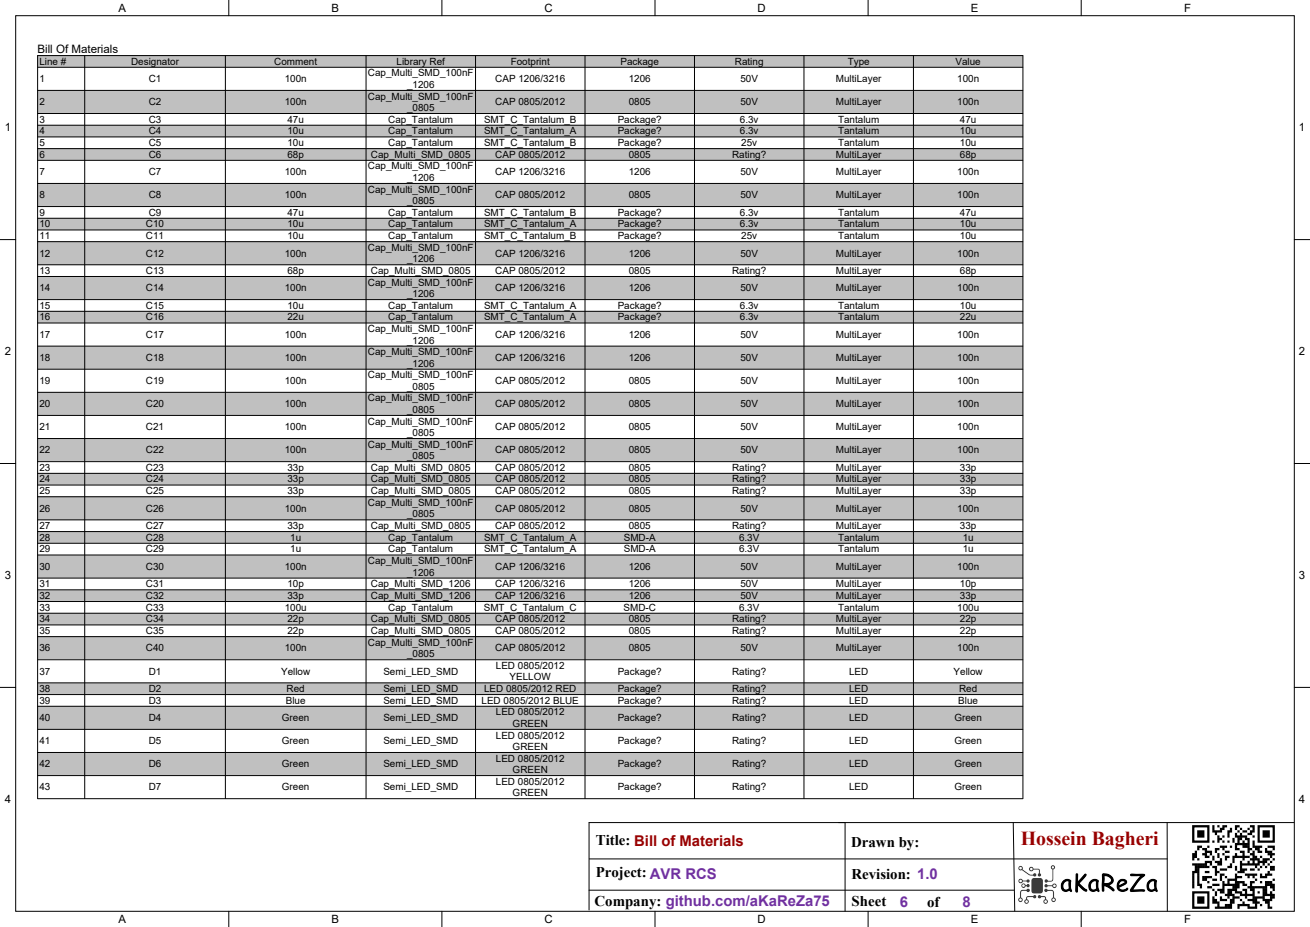
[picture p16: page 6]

Line # 123456789 | C2 | 100n | Cap_Multi_SMD_100nF _0805 | CAP 0805/2012 | 0805 | 50V | MultiLayer | 100n

Designator | Comment | Library Ref | Footprint | Package | Rating | Type | Value
C1 | 100n | Cap_Multi_SMD_100nF _1206 | CAP 1206/3216 | 1206 | 50V | MultiLayer | 100n

C3 | 47u | Cap_Tantalum | SMT_C_Tantalum_B | Package? | 6.3v | Tantalum | 47u
C4 | 10u | Cap_Tantalum | SMT_C_Tantalum_A | Package? | 6.3v | Tantalum | 10u
C5 | 10u | Cap_Tantalum | SMT_C_Tantalum_B | Package? | 25v | Tantalum | 10u
C6 | 68p | Cap_Multi_SMD_0805 | CAP 0805/2012 | 0805 | Rating? | MultiLayer | 68p
C7 | 100n | Cap_Multi_SMD_100nF _1206 | CAP 1206/3216 | 1206 | 50V | MultiLayer | 100n

C8 | 100n | Cap_Multi_SMD_100nF _0805 | CAP 0805/2012 | 0805 | 50V | MultiLayer | 100n

C9 | 47u | Cap_Tantalum | SMT_C_Tantalum_B | Package? | 6.3v | Tantalum | 47u

10 | C10 | 10u | Cap_Tantalum | SMT_C_Tantalum_A | Package? | 6.3v | Tantalum | 10u
11 | C11 | 10u | Cap_Tantalum | SMT_C_Tantalum_B | Package? | 25v | Tantalum | 10u
12 | C12 | 100n | Cap_Multi_SMD_100nF _1206 | CAP 1206/3216 | 1206 | 50V | MultiLayer | 100n

13 | C13 | 68p | Cap_Multi_SMD_0805 | CAP 0805/2012 | 0805 | Rating? | MultiLayer | 68p
14 | C14 | 100n | Cap_Multi_SMD_100nF _1206 | CAP 1206/3216 | 1206 | 50V | MultiLayer | 100n

15 | C15 | 10u | Cap_Tantalum | SMT_C_Tantalum_A | Package? | 6.3v | Tantalum | 10u
16 | C16 | 22u | Cap_Tantalum | SMT_C_Tantalum_A | Package? | 6.3v | Tantalum | 22u
17 | C17 | 100n | Cap_Multi_SMD_100nF _1206 | CAP 1206/3216 | 1206 | 50V | MultiLayer | 100n

18 | C18 | 100n | Cap_Multi_SMD_100nF _1206 | CAP 1206/3216 | 1206 | 50V | MultiLayer | 100n

19 | C19 | 100n | Cap_Multi_SMD_100nF _0805 | CAP 0805/2012 | 0805 | 50V | MultiLayer | 100n

20 | C20 | 100n | Cap_Multi_SMD_100nF _0805 | CAP 0805/2012 | 0805 | 50V | MultiLayer | 100n

21 | C21 | 100n | Cap_Multi_SMD_100nF _0805 | CAP 0805/2012 | 0805 | 50V | MultiLayer | 100n

22 | C22 | 100n | Cap_Multi_SMD_100nF _0805 | CAP 0805/2012 | 0805 | 50V | MultiLayer | 100n

23 | C23 | 33p | Cap_Multi_SMD_0805 | CAP 0805/2012 | 0805 | Rating? | MultiLayer | 33p
24 | C24 | 33p | Cap_Multi_SMD_0805 | CAP 0805/2012 | 0805 | Rating? | MultiLayer | 33p
25 | C25 | 33p | Cap_Multi_SMD_0805 | CAP 0805/2012 | 0805 | Rating? | MultiLayer | 33p
26 | C26 | 100n | Cap_Multi_SMD_100nF _0805 | CAP 0805/2012 | 0805 | 50V | MultiLayer | 100n

27 | C27 | 33p | Cap_Multi_SMD_0805 | CAP 0805/2012 | 0805 | Rating? | MultiLayer | 33p
28 | C28 | 1u | Cap_Tantalum | SMT_C_Tantalum_A | SMD-A | 6.3V | Tantalum | 1u
29 | C29 | 1u | Cap_Tantalum | SMT_C_Tantalum_A | SMD-A | 6.3V | Tantalum | 1u
30 | C30 | 100n | Cap_Multi_SMD_100nF _1206 | CAP 1206/3216 | 1206 | 50V | MultiLayer | 100n

31 | C31 | 10p | Cap_Multi_SMD_1206 | CAP 1206/3216 | 1206 | 50V | MultiLayer | 10p
32 | C32 | 33p | Cap_Multi_SMD_1206 | CAP 1206/3216 | 1206 | 50V | MultiLayer | 33p
33 | C33 | 100u | Cap_Tantalum | SMT_C_Tantalum_C | SMD-C | 6.3V | Tantalum | 100u
34 | C34 | 22p | Cap_Multi_SMD_0805 | CAP 0805/2012 | 0805 | Rating? | MultiLayer | 22p
35 | C35 | 22p | Cap_Multi_SMD_0805 | CAP 0805/2012 | 0805 | Rating? | MultiLayer | 22p
36 | C40 | 100n | Cap_Multi_SMD_100nF _0805 | CAP 0805/2012 | 0805 | 50V | MultiLayer | 100n

37 | D1 | Yellow | Semi_LED_SMD | LED 0805/2012 YELLOW | Package? | Rating? | LED | Yellow

38 | D2 | Red | Semi_LED_SMD | LED 0805/2012 RED | Package? | Rating? | LED | Red
39 | D3 | Blue | Semi_LED_SMD | LED 0805/2012 BLUE | Package? | Rating? | LED | Blue
40 | D4 | Green | Semi_LED_SMD | LED 0805/2012 GREEN | Package? | Rating? | LED | Green

41 | D5 | Green | Semi_LED_SMD | LED 0805/2012 GREEN | Package? | Rating? | LED | Green

42 | D6 | Green | Semi_LED_SMD | LED 0805/2012 GREEN | Package? | Rating? | LED | Green

43 | D7 | Green | Semi_LED_SMD | LED 0805/2012 GREEN | Package? | Rating? | LED | Green

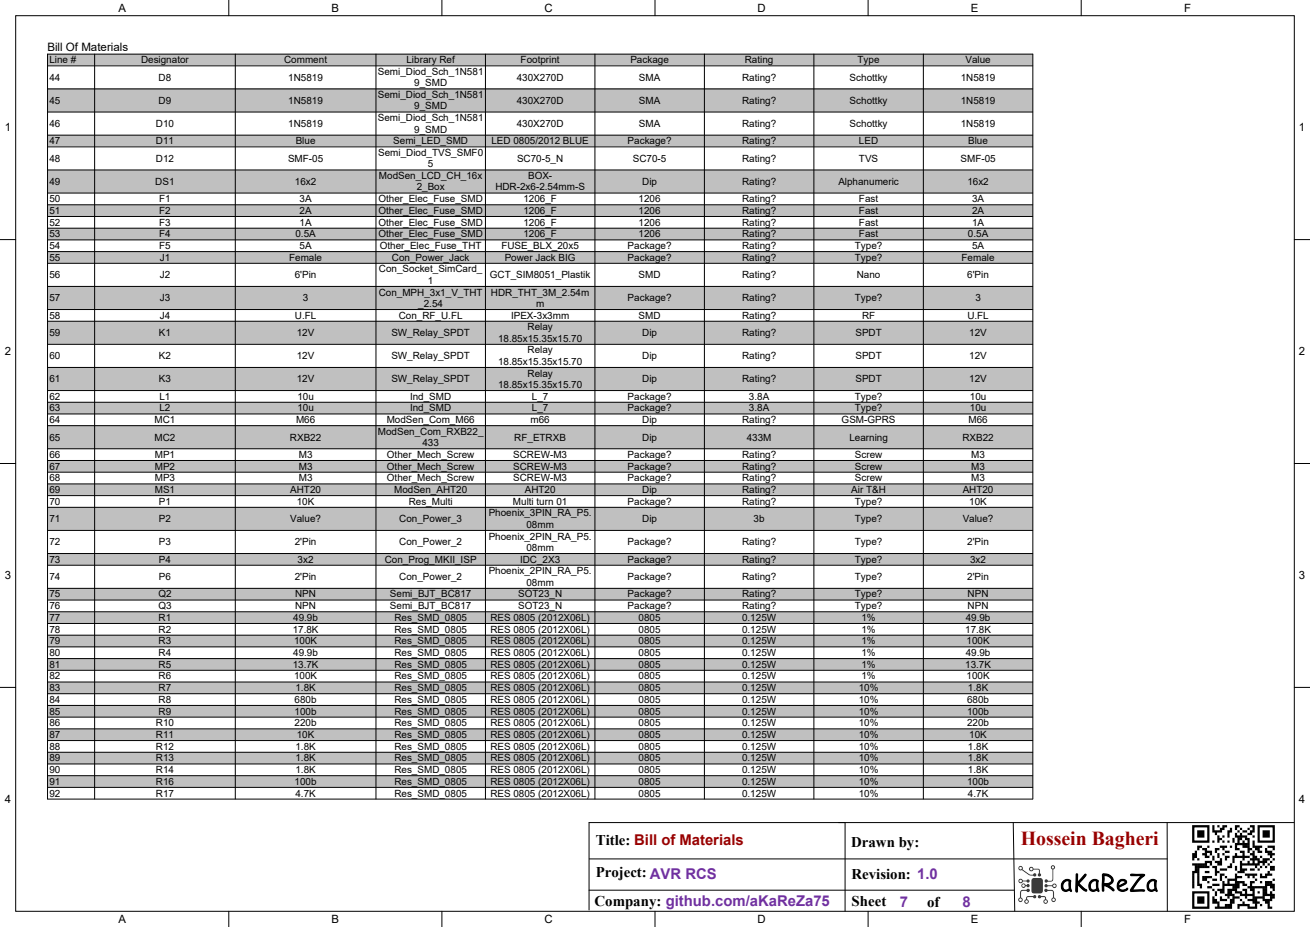
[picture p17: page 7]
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

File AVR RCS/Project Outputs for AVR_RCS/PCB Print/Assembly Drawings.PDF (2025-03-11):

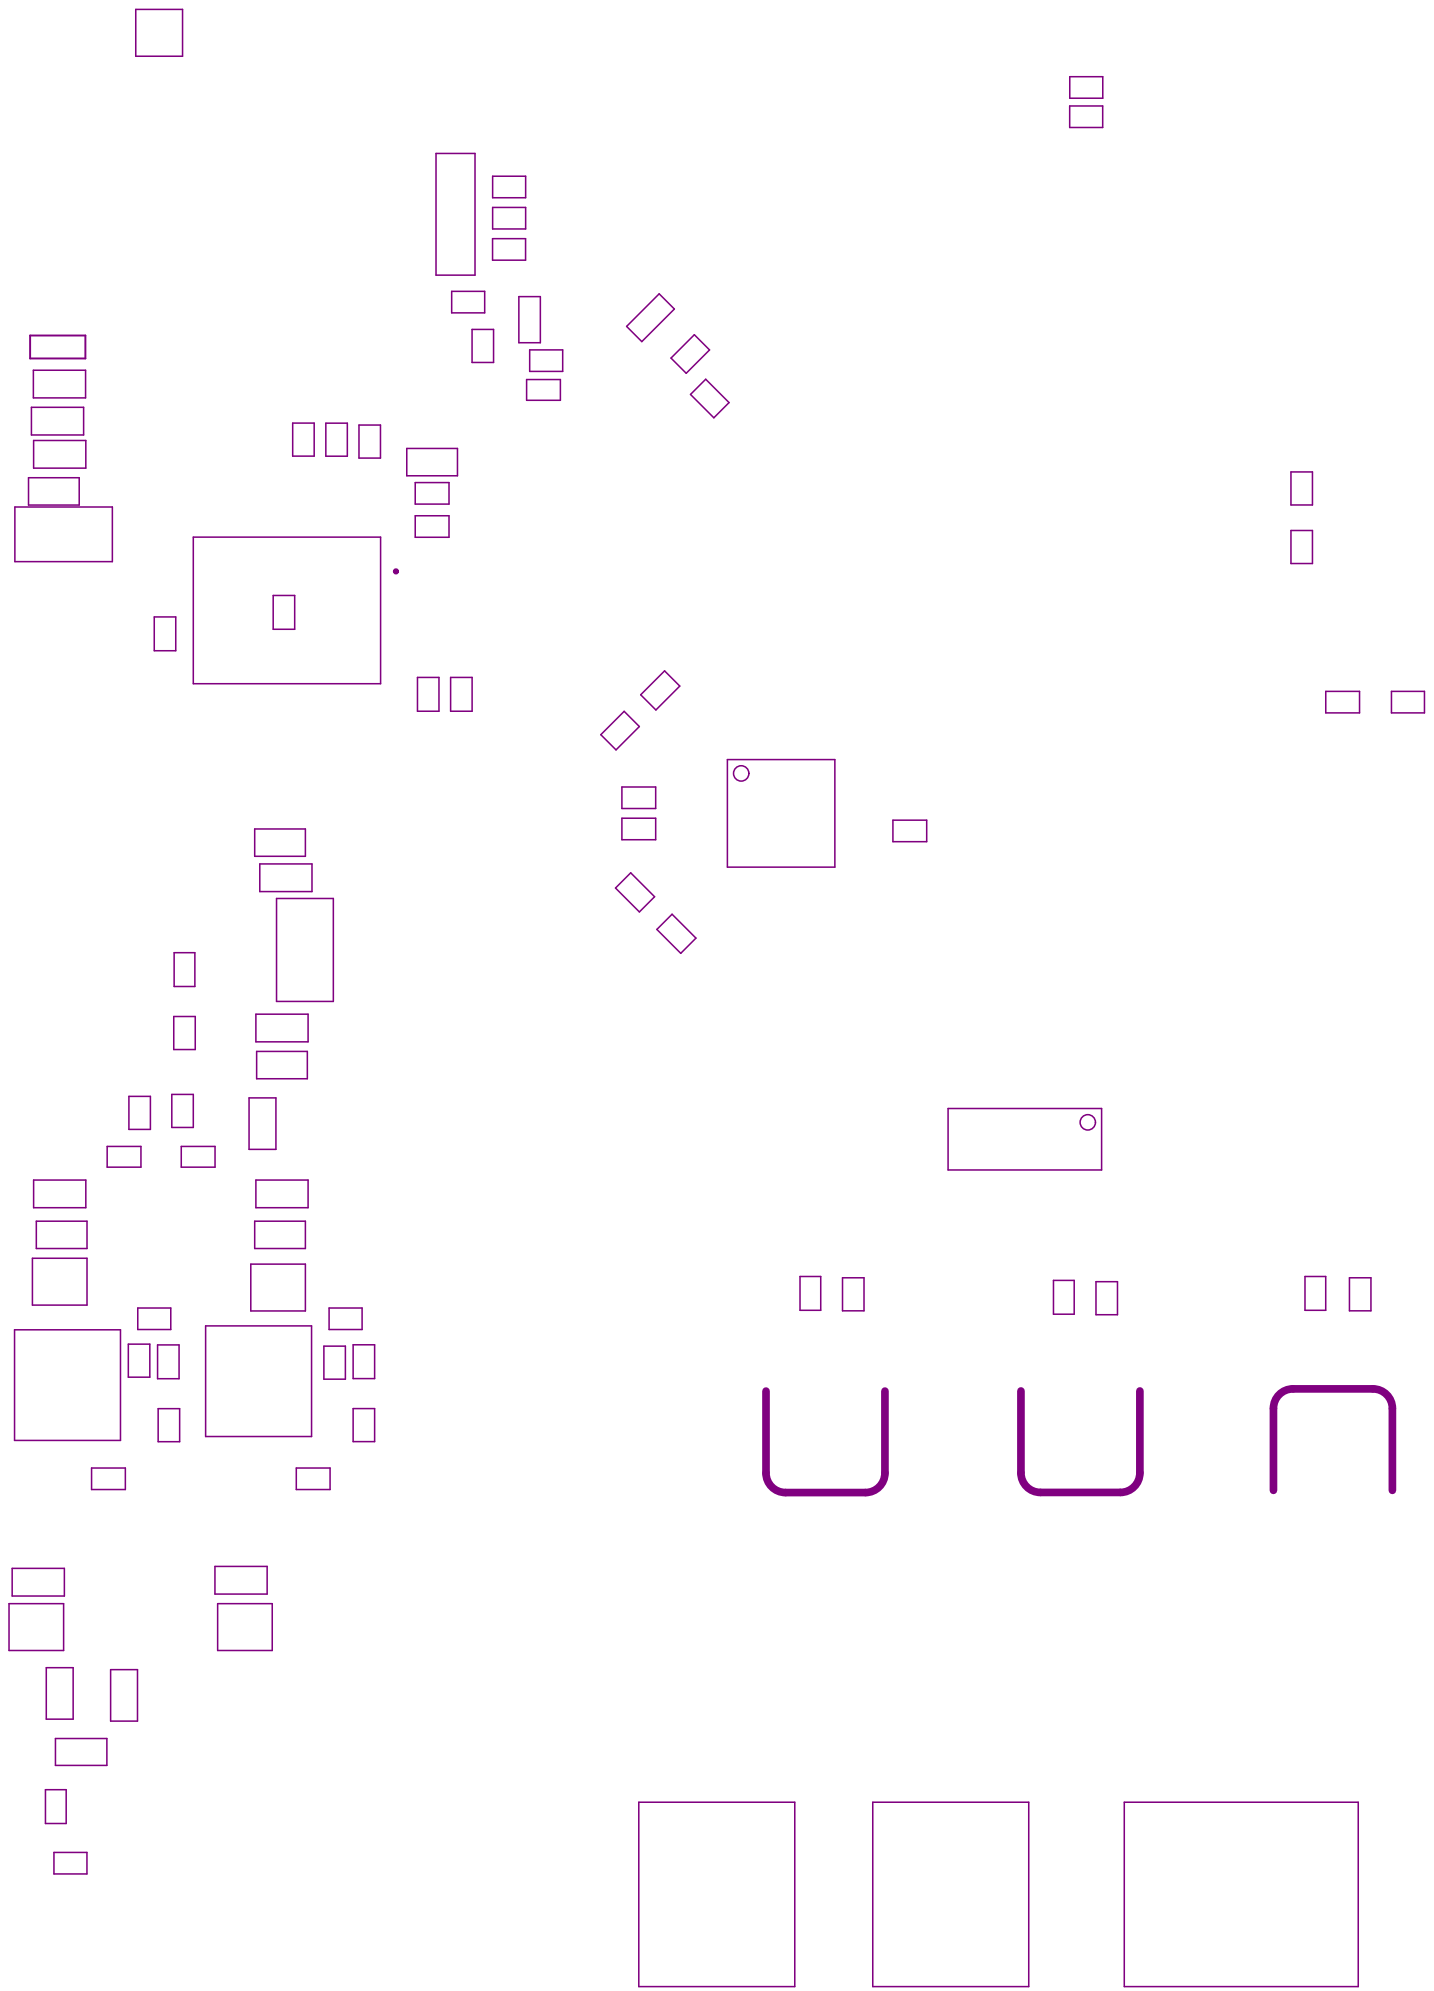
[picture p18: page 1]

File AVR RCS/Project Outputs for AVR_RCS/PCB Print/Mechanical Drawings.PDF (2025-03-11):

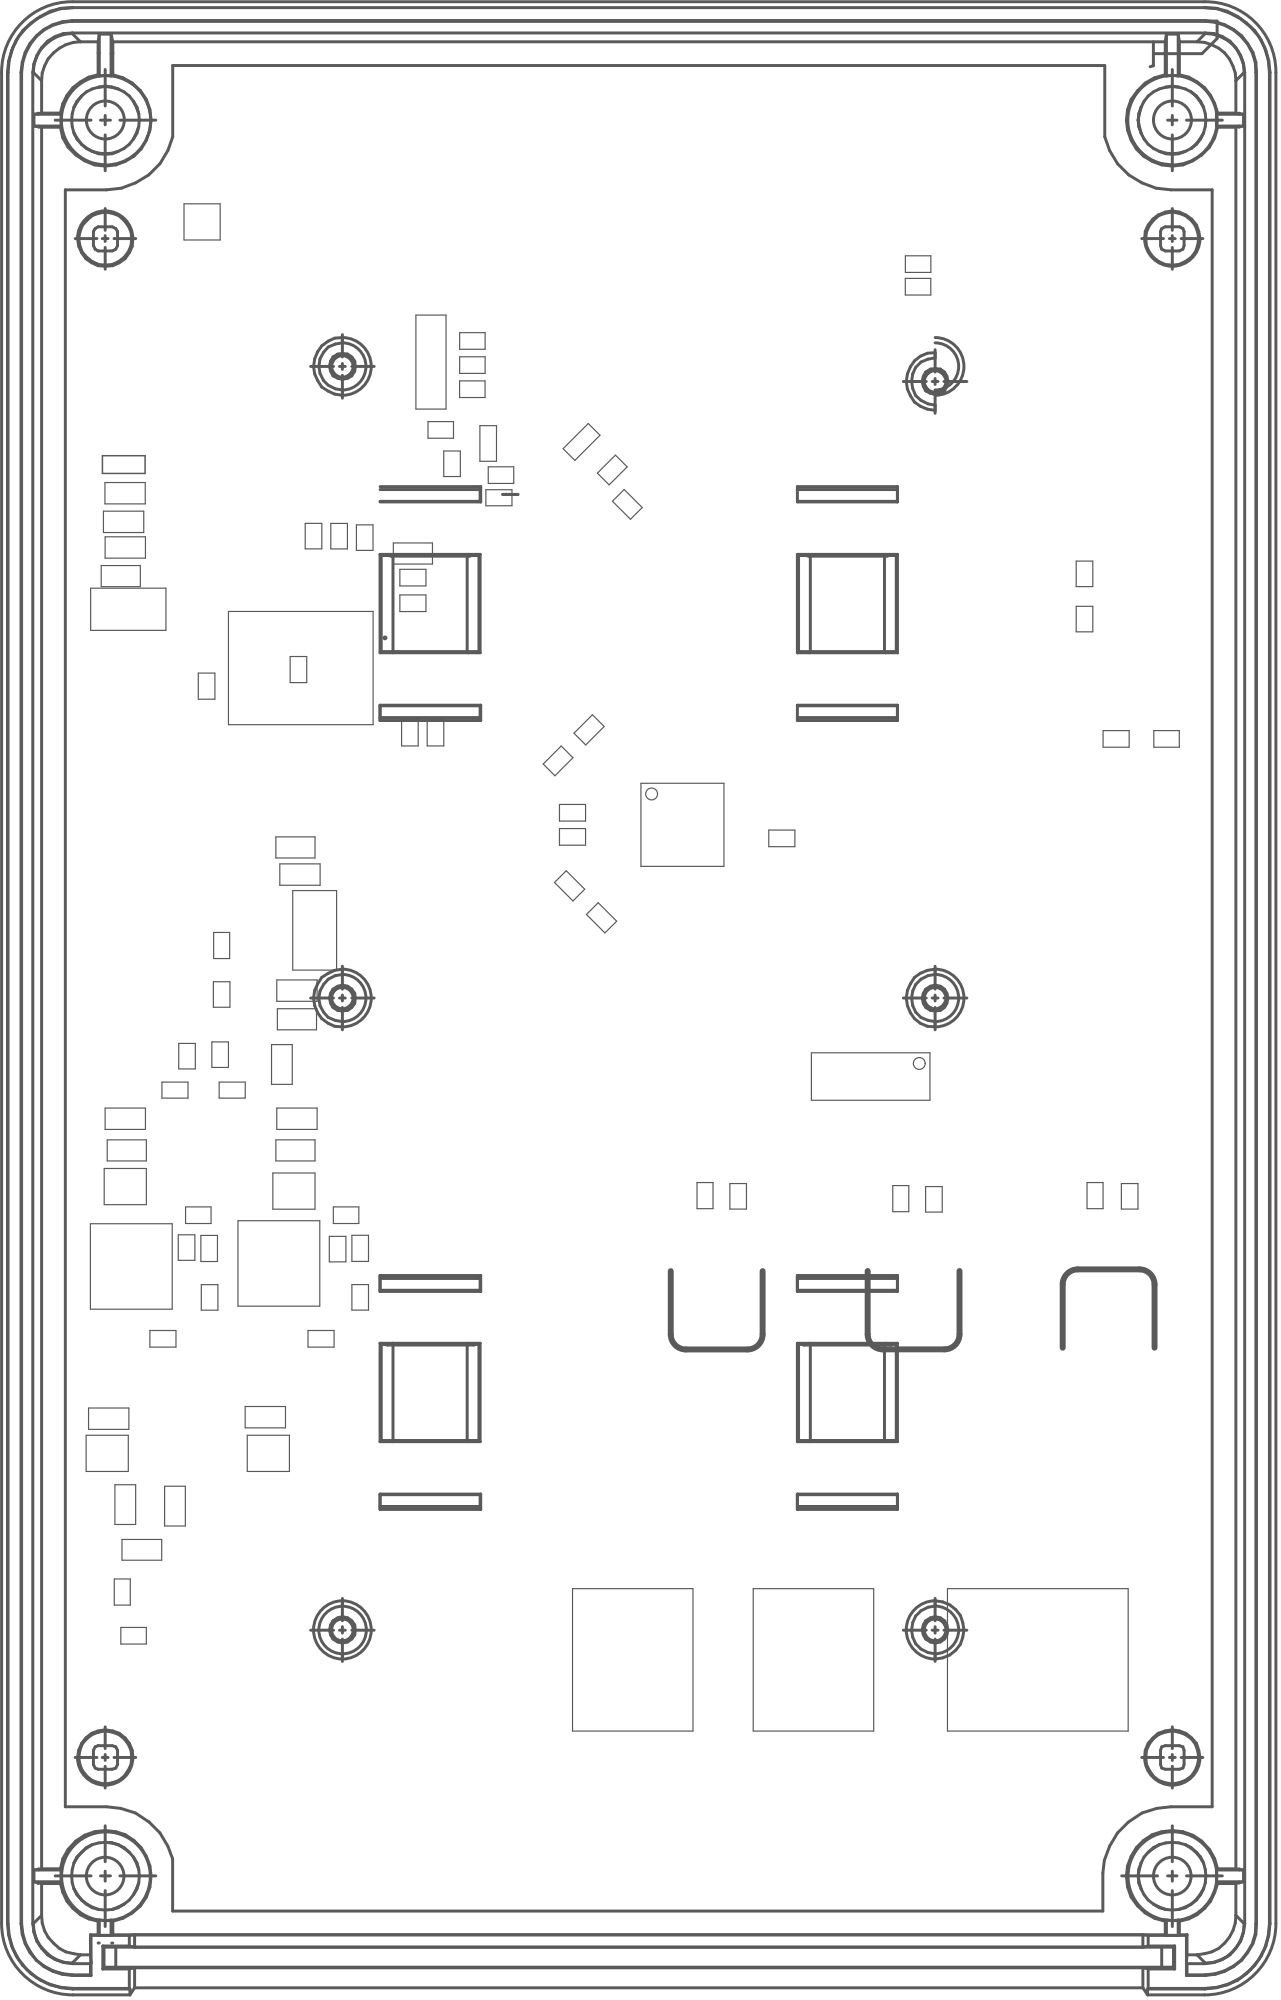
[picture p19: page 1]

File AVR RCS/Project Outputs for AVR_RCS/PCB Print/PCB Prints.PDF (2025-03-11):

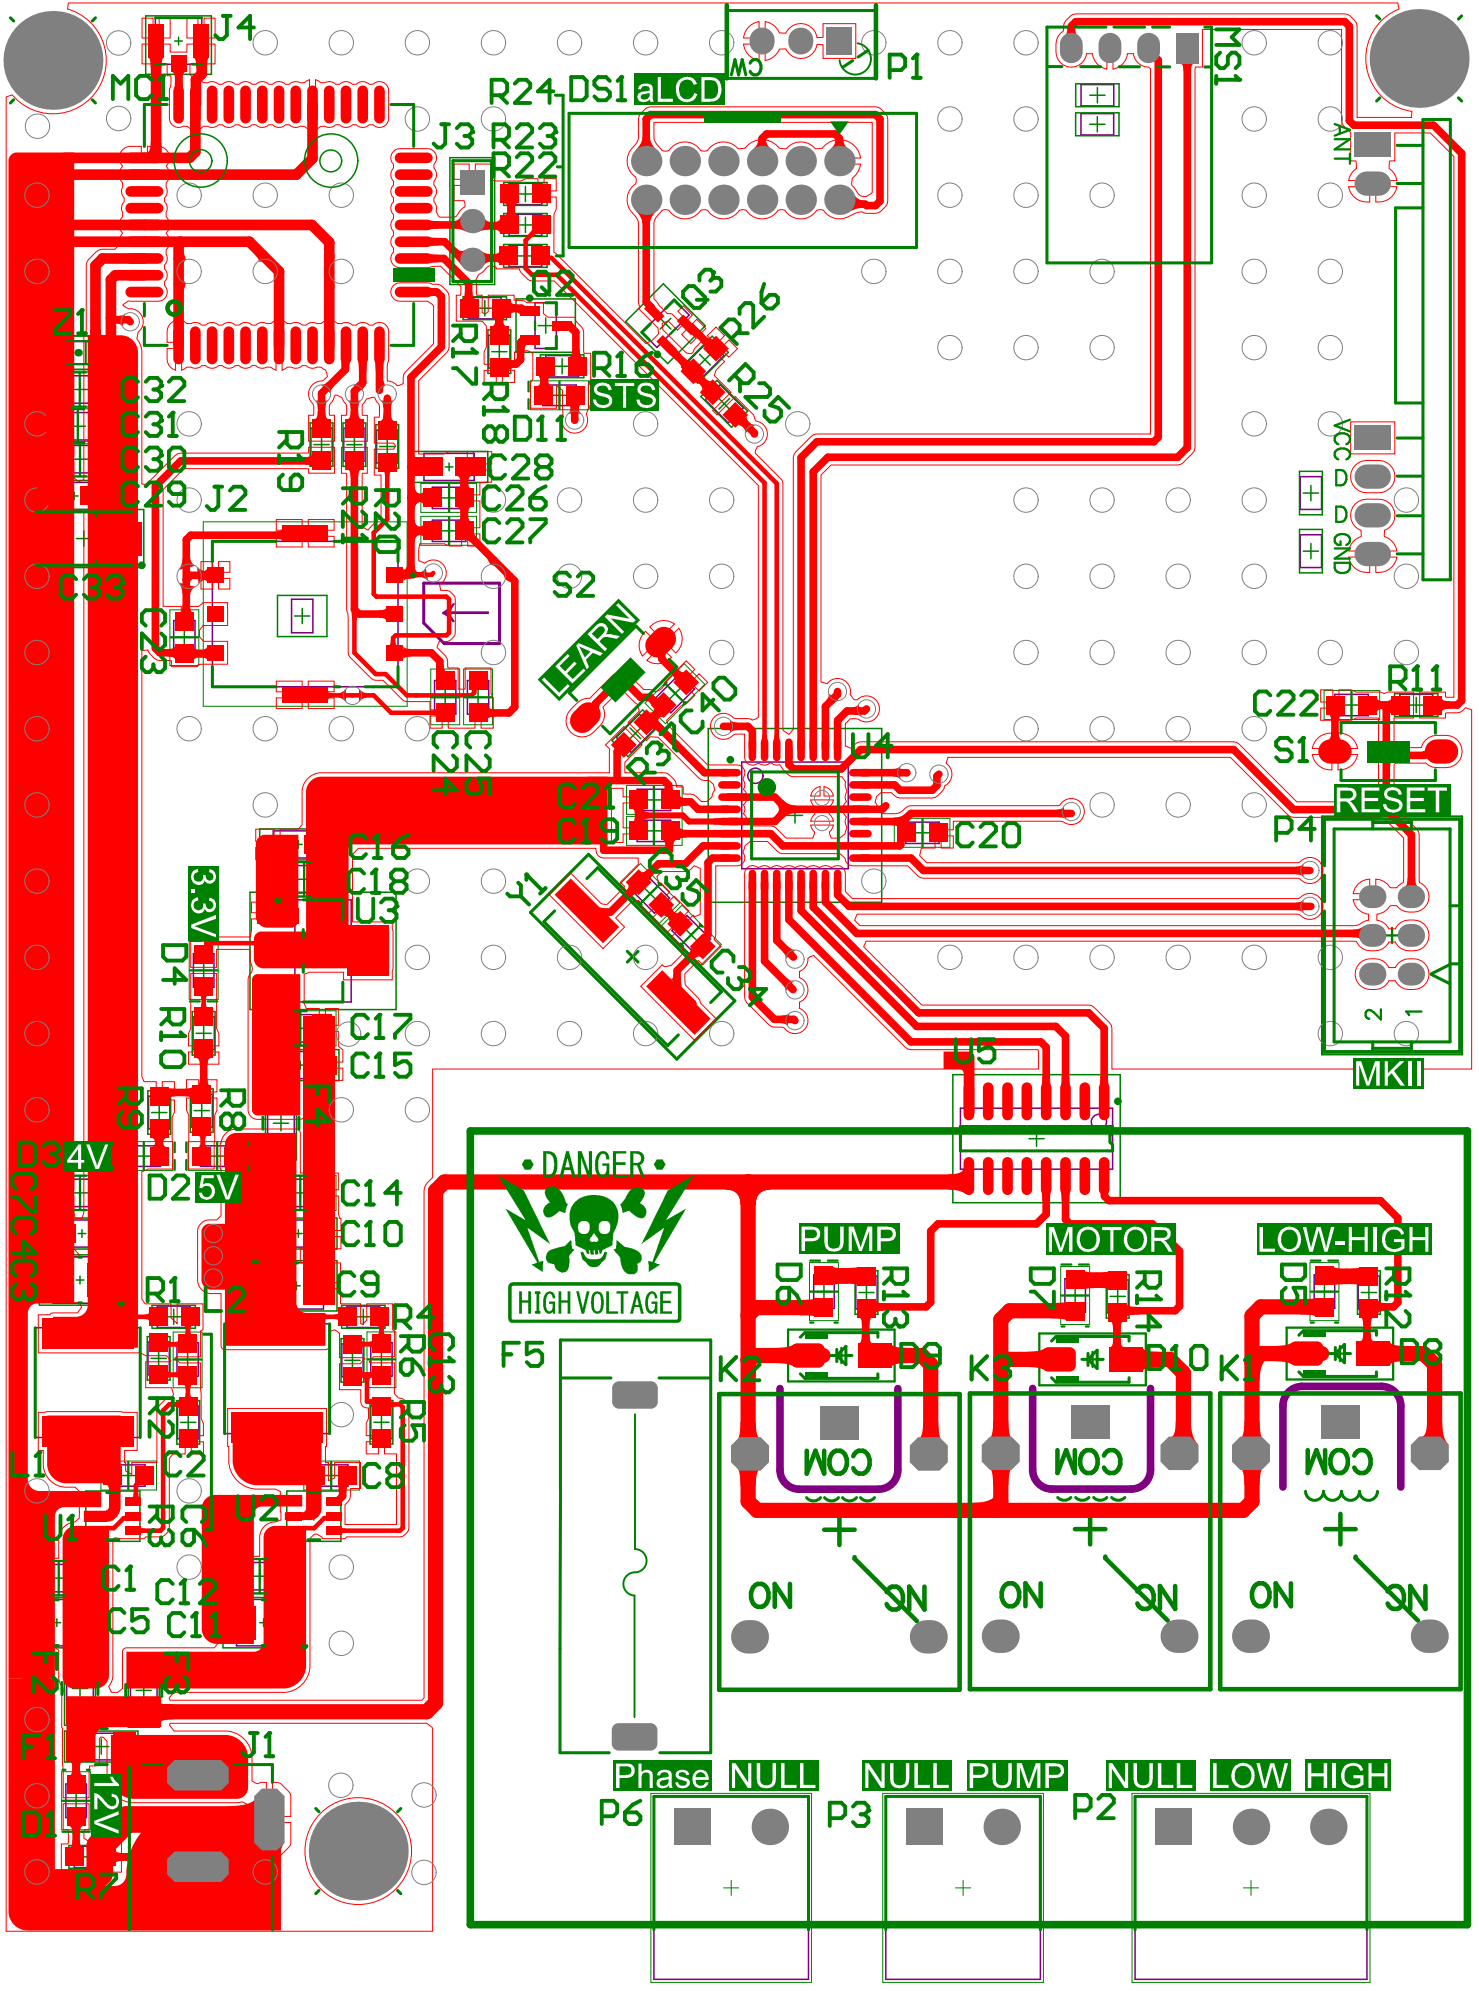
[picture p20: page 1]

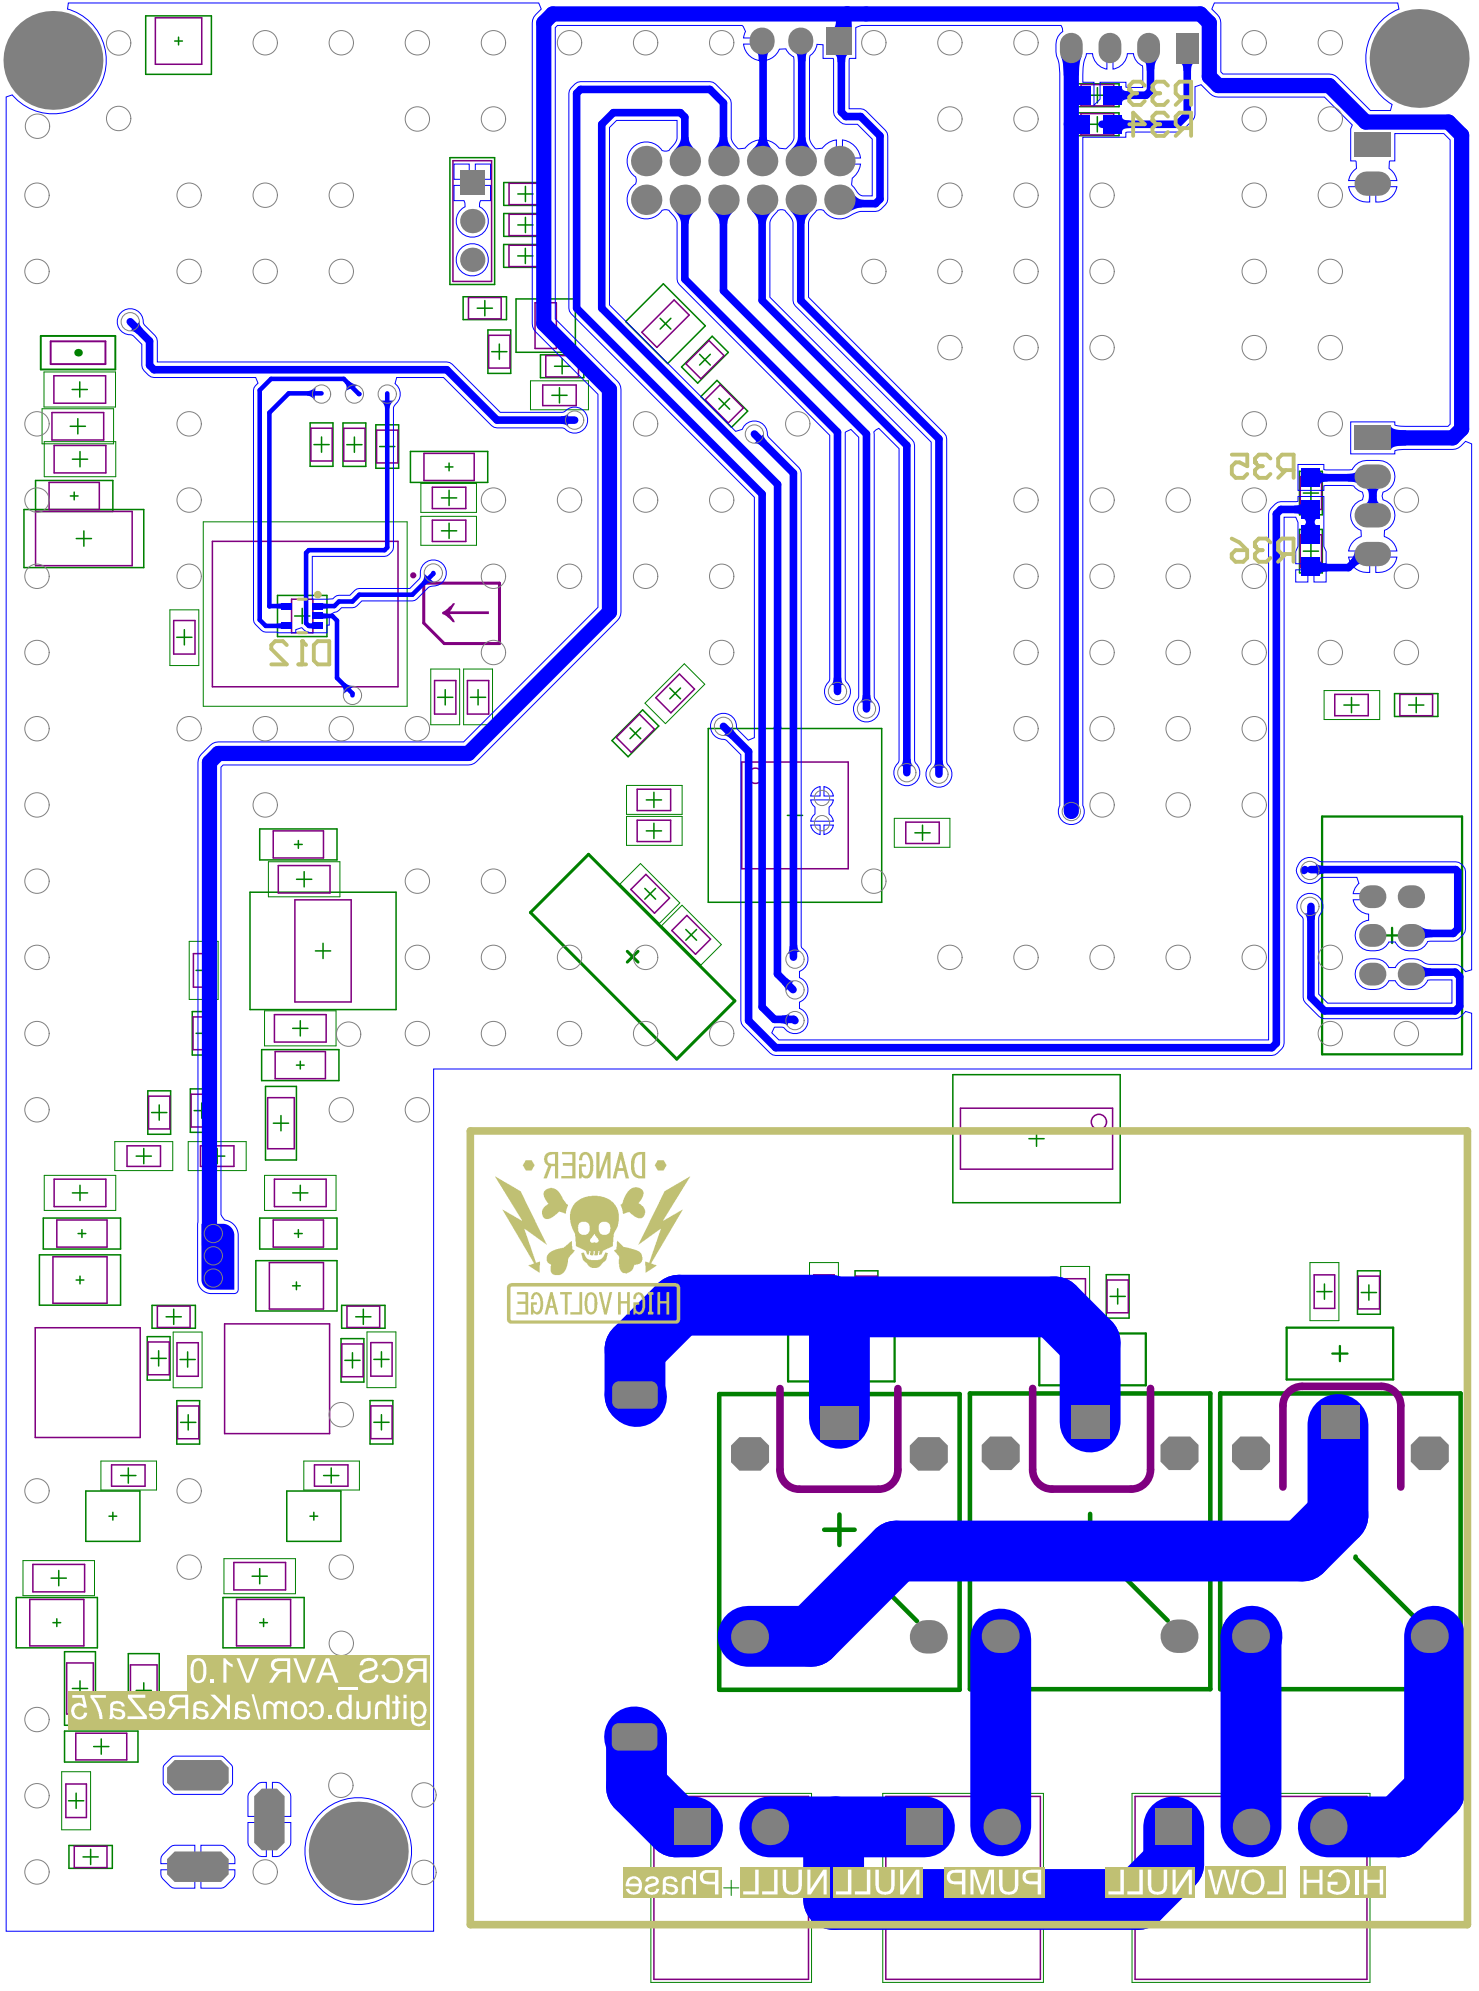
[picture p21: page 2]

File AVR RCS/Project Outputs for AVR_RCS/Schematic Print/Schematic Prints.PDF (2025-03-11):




1 8







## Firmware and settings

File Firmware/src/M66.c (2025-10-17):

/**
 * @file     M66.c
 * @brief    M66 GSM Module Communication Implementation
 * @note     This source file contains the implementation of functions used to initialize,
 *           configure, and communicate with the M66 GSM module, including SMS handling
 *           and AT command transmission.
 * 
 * @author   Hossein Bagheri
 * @github   https://github.com/aKaReZa75
 * 
 * @note     For more information and examples, visit the project repository:
 *           https://github.com/aKaReZa75/AVR_M66
 * 
 * @note     This library uses the USART peripheral for communication. See USART library at:
 *           https://github.com/aKaReZa75/AVR_USART
 */
#include "M66.h"


extern volatile bool usart_RxFlag;   /**< True: Data has been received completely */   
extern char usart_RxBuffer[__usart_RxBufferSize]; /* Buffer to store received data, with defined size */
extern GSM_StartUp_Flags_T GSM_StartUp_Flags;
extern GSM_Init_State_T GSM_Init_State;
extern GSM_Init_Flags_T GSM_Init_Flags;
extern SMS_CMD_Type_T   SMS_CMD_Type;
extern Outputs_T Outputs;

#define SMS_Authorized_Number "+989355282124"
#define SMS_scanSet_Index     "\r\n+CMTI: \"SM\",%hhu\r\n"
#define SMS_scanSet_Number    "\r\n+CMGR: \"%*[^\"]\",\"%[^\"]\""
#define SMS_scanSet_Content   "\r\n+CMGR: \"%*[^\"]\",\"%*[^\"]\",\"\",\"%*[^\"]\"\r\n%[^\r]\r\n"
#define SMS_CMD_Pump_OFF_Motor_OFF   "RCS+OC=0,0"
#define SMS_CMD_Pump_ON_Motor_OFF    "RCS+OC=1,0"
#define SMS_CMD_Pump_ON_Motor_LOW    "RCS+OC=1,1"
#define SMS_CMD_Pump_ON_Motor_HIGH   "RCS+OC=1,2"
#define SMS_CMD_Pump_OFF_Motor_LOW   "RCS+OC=0,1"
#define SMS_CMD_Pump_OFF_Motor_HIGH  "RCS+OC=0,2"

/**
 * @brief Initializes the M66 GSM module
 * @details Performs module startup and configuration sequence
 * @return M66_Res_T Status of initialization (OK, ERR, or TimeOut)
 */
M66_Res_T M66_Init(void)
{
    M66_Res_T _Res = M66_Res_ERR;

    // First attempt to start up the module
    _Res = M66_Startup();
    if(_Res != M66_Res_OK)
    {
        return _Res;
    };

    // If startup successful, proceed with configuration
    _Res = M66_Config();
    if(_Res != M66_Res_OK)
    {
        return _Res;
    };

    return M66_Res_OK;
};


/**
 * @brief Performs the M66 module startup sequence
 * @details Sends restart command and waits for all readiness indicators
 * @return M66_Res_T Status of startup process
 */
M66_Res_T M66_Startup(void)
{
    // Check for basic readiness
    if(strstr(usart_RxBuffer, "RDY") != NULL)
    {
        GSM_StartUp_Flags.bits.Ready = true;
    };

    // Check for full functionality
    if(strstr(usart_RxBuffer, "+CFUN: 1") != NULL)
    {
        GSM_StartUp_Flags.bits.CFUN = true;
    };

    // Check SIM card status
    if(strstr(usart_RxBuffer, "+CPIN: READY") != NULL)
    {
        GSM_StartUp_Flags.bits.CPIN = true;
    };    

    // Check call readiness
    if(strstr(usart_RxBuffer, "Call Ready") != NULL)
    {
        GSM_StartUp_Flags.bits.Call = true;
    };    

    // Check SMS readiness
    if(strstr(usart_RxBuffer, "SMS Ready") != NULL)
    {
        GSM_StartUp_Flags.bits.SMS = true;
    }; 

    GSM_StartUp_Flags.bits.Result = GSM_StartUp_Flags.bits.Ready
                                  & GSM_StartUp_Flags.bits.CFUN
                                  & GSM_StartUp_Flags.bits.CPIN
                                  & GSM_StartUp_Flags.bits.Call
                                  & GSM_StartUp_Flags.bits.SMS;

    return M66_Res_OK;
};


/**
 * @brief Configures the M66 module with default settings
 * @details Sets up echo, functionality mode, SMS format, and other parameters
 * @return M66_Res_T Status of configuration process
 */
M66_Res_T M66_Config(void)
{
    static GSM_Init_State_T GSM_Init_State_Last = GSM_Init_Func;
    switch (GSM_Init_State)
    {
        case GSM_Init_Echo: // Disable command echo
            if(GSM_Init_State_Last != GSM_Init_Echo)
            {
                usart_Putsln(__M66_CMD_EchoOff);
                GSM_Init_State_Last = GSM_Init_Echo;
            }
            else
            {
                if(usart_RxFlag == true)
                {
                    if(strstr(usart_RxBuffer, "ATE0") != NULL)
                    {
                        GSM_Init_Flags.bits.Echo = true;
                    }
                    else if(strstr(usart_RxBuffer, __M66_Okey) != NULL)
                    {
                        GSM_Init_Flags.bits.Echo = true;
                    }
                    else
                    {
                        GSM_Init_Flags.bits.Echo = false;
                    };
                    GSM_Init_State = GSM_Init_Func;
                };
            };
        break;

        case GSM_Init_Func: // Enable full functionality
            if(GSM_Init_State_Last != GSM_Init_Func)
            {
                usart_Putsln(__M66_CMD_fullFunc);
                GSM_Init_State_Last = GSM_Init_Func;
            }
            else
            {
                if(usart_RxFlag == true)
                {                
                    if(strstr(usart_RxBuffer, __M66_Okey) != NULL)
                    {
                        GSM_Init_Flags.bits.Func = true;
                    }
                    else
                    {
                        GSM_Init_Flags.bits.Func = false;
                    };
                    GSM_Init_State = GSM_Init_Text;
                };
            };
        break;
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

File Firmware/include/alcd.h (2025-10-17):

/**
 ******************************************************************************
 * @file     alcd.h
 * @brief    16x2 Alphanumeric LCD display library header for AVR
 * 
 * @author   Hossein Bagheri
 * @github   https://github.com/aKaReZa75
 * 
 * @note     This header file provides definitions for:
 *           - HD44780 compatible LCD controller commands
 *           - GPIO pin mappings for 4-bit parallel interface
 *           - Display control functions
 *           - Custom character (CGRAM) support
 * 
 * @note     For detailed documentation with examples, visit:
 *           https://github.com/aKaReZa75/AVR_Display_aLCD
 ******************************************************************************
 */
#ifndef _alcd_H_
#define _alcd_H_

#include "aKaReZa.h"


/* ============================================================================
 *                         FEATURE CONFIGURATION
 * ============================================================================ */

/* -------------------------------------------------------
 * @brief Enable/disable backlight control feature
 * @note Set to true to enable backlight control pin
 * ------------------------------------------------------- */
#define __alcd_useBL  true


/* ============================================================================
 *                         GPIO PIN DEFINITIONS
 * ============================================================================
 * @note These definitions are for AVR compatibility
 *       For STM32, use HAL GPIO functions in implementation
 * ---------------------------------------------------------------------------- */

/* -------------------------------------------------------
 * @brief LCD RS (Register Select) pin configuration
 * @note RS=0: Command mode, RS=1: Data mode
 * ------------------------------------------------------- */
#define __alcd_RS_Config   DDRC      /**< Register to configure the RS pin direction */
#define __alcd_RS_Control  PORTC     /**< Port register to control the RS pin */
#define __alcd_RS_Pin      0         /**< Pin number for the RS pin */

/* -------------------------------------------------------
 * @brief LCD EN (Enable) pin configuration
 * @note Enable signal triggers data latch on LCD
 * ------------------------------------------------------- */
#define __alcd_EN_Config   DDRC      /**< Register to configure the EN pin direction */
#define __alcd_EN_Control  PORTC     /**< Port register to control the EN pin */
#define __alcd_EN_Pin      1         /**< Pin number for the EN pin */

/* -------------------------------------------------------
 * @brief LCD DB4 (Data Bit 4) pin configuration
 * ------------------------------------------------------- */
#define __alcd_DB4_Config  DDRD      /**< Register to configure the DB4 pin direction */
#define __alcd_DB4_Control PORTD     /**< Port register to control the DB4 pin */
#define __alcd_DB4_Pin     5         /**< Pin number for the DB4 pin */

/* -------------------------------------------------------
 * @brief LCD DB5 (Data Bit 5) pin configuration
 * ------------------------------------------------------- */
#define __alcd_DB5_Config  DDRC      /**< Register to configure the DB5 pin direction */
#define __alcd_DB5_Control PORTC     /**< Port register to control the DB5 pin */
#define __alcd_DB5_Pin     2         /**< Pin number for the DB5 pin */

/* -------------------------------------------------------
 * @brief LCD DB6 (Data Bit 6) pin configuration
 * ------------------------------------------------------- */
#define __alcd_DB6_Config  DDRD      /**< Register to configure the DB6 pin direction */
#define __alcd_DB6_Control PORTD     /**< Port register to control the DB6 pin */
#define __alcd_DB6_Pin     6         /**< Pin number for the DB6 pin */

/* -------------------------------------------------------
 * @brief LCD DB7 (Data Bit 7) pin configuration
 * ------------------------------------------------------- */
#define __alcd_DB7_Config  DDRC      /**< Register to configure the DB7 pin direction */
#define __alcd_DB7_Control PORTC     /**< Port register to control the DB7 pin */
#define __alcd_DB7_Pin     3         /**< Pin number for the DB7 pin */

/* -------------------------------------------------------
 * @brief LCD Backlight pin configuration (Optional)
 * @note Only defined if __alcd_useBL is enabled
 * ------------------------------------------------------- */
#ifdef __alcd_useBL
    #define __alcd_BL_Config   DDRD  /**< Register to configure the backlight pin direction */
    #define __alcd_BL_Control  PORTD /**< Port register to control the backlight pin */
    #define __alcd_BL_Pin      7     /**< Pin number for the backlight pin */
#endif


/* ============================================================================
 *                         TIMING CONFIGURATION
 * ============================================================================ */

/* -------------------------------------------------------
 * @brief Delay function macro
 * @note Uses delay_us() from aKaReZa.h
 * ------------------------------------------------------- */
#define __alcd_delay(_delayValue)  _delay_us(_delayValue)

/* -------------------------------------------------------
 * @brief Timing constants in microseconds
 * ------------------------------------------------------- */
#define __alcd_delay_CMD      50      /**< Standard command execution time */
#define __alcd_delay_modeSet  5000    /**< Mode setting and initialization delay */
#define __alcd_delay_powerON  50000   /**< Power-on stabilization delay */


/* ============================================================================
 *                         LCD DISPLAY CONFIGURATION
 * ============================================================================ */

/* -------------------------------------------------------
 * @brief Command/Data selection for RS pin
 * ------------------------------------------------------- */
#define __alcd_writeCmd   0  /**< RS=0: Send command to LCD */
#define __alcd_writeData  1  /**< RS=1: Send data to LCD */

/* -------------------------------------------------------
 * @brief LCD dimensions
 * ------------------------------------------------------- */
#define __alcd_max_x  16  /**< Maximum columns (16 characters per line) */
#define __alcd_max_y  2   /**< Maximum rows (2 lines) */


/* ============================================================================
 *                         HD44780 COMMAND DEFINITIONS
 * ============================================================================ */
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

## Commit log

2024-07-06 Create a raw project
    [PCB.PcbDoc, PCB_RawPrj.PrjPcb, Sheet1.SchDoc]
2024-07-06 Change schematic template
    [PCB.PcbDoc, PCB_RawPrj.PrjPcb, Sheet1.SchDoc]
2024-07-06 Create Schmatic files
    [Controller.SchDoc, GSM.SchDoc, Inputs.SchDoc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]
2024-07-06 Chnage Schematic Template
    [Controller.SchDoc, GSM.SchDoc, Inputs.SchDoc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]
2024-07-06 Chnage PCB Structure
2024-07-07 Change project name
    [AVR_RCS.PrjPcb]
2024-07-16 add 12V input jack
    [Supply.SchDoc]
2024-07-16 Design 4V Regulator
    [Supply.SchDoc]
2024-07-16 design 5V Regulator
    [Supply.SchDoc]
2024-07-16 design 3.3V Regulator
    [Supply.SchDoc]
2024-07-16 add some fuses
    [Supply.SchDoc]
2024-07-16 add voltage indicators
    [Supply.SchDoc]
2024-07-18 add Fuses, Ress, LEDs, Reg,...
2024-07-19 led resitors for 20mA, 5v regulator component values
    [Supply.SchDoc]
2024-07-19 Calculate resistors of LED & Vlaue of TPS54302 For 5 Volt Output
    [Supply.SchDoc, TPS54302.xlsx]
2024-07-20 was coreccted Values of LED Resistors and Vaue of LPT2
    [Supply.SchDoc]
2024-07-20 EDIT Values of LED Resistors for 5mA
    [Supply.SchDoc, TPS54302.xlsx]
2024-07-22 change LED resistors value
    [Supply.SchDoc]
2024-07-22 chnage 5v regulator values
    [Supply.SchDoc]
2024-07-22 add 'b' to Resistors
    [Supply.SchDoc]
2024-07-22 add led Resistors
2024-07-25 add microController
    [Controller.SchDoc]
2024-07-25 add 100nF Caps
    [Controller.SchDoc]
2024-07-25 add Reset switch
    [Controller.SchDoc]
2024-07-25 add Programmer Conector
    [Controller.SchDoc]
2024-07-25 add relays and output Terminal
    [Outputs.SchDoc]
2024-07-25 add fuse for phase
    [Outputs.SchDoc]
2024-07-25 add LED status for relays
    [Outputs.SchDoc]
2024-07-25 add fly wheel diods
    [Outputs.SchDoc]
2024-07-25 add main schematic
    [AVR_RCS.PrjPcb, Main.SchDoc, Outputs.SchDoc]
2024-07-25 add Suplly ports
    [Controller.SchDoc, Main.SchDoc, Supply.SchDoc]
2024-07-25 add Suplly port to Controller
    [Controller.SchDoc, Main.SchDoc]
2024-07-25 add input ports for Outputs
    [Main.SchDoc, Outputs.SchDoc]
2024-07-25 add signal pins
    [Controller.SchDoc, Main.SchDoc, Outputs.SchDoc]
2024-07-25 add no ERC to unconnected pins
    [Controller.SchDoc, Main.SchDoc, Outputs.SchDoc]
2024-07-25 create a AVR_RCS library
    [Main.SchDoc, PCB.PcbDoc]
2024-07-25 save prj
    [AVR_RCS.PrjPcb]
2024-08-23 add aLCD
    [Controller.SchDoc, aLCD.SchDoc]
2024-08-23 add aLCD harness
    [AVR_RCS.PrjPcb, aLCD.SchDoc]
2024-08-23 add motor harness
    [AVR_RCS.PrjPcb, Controller.SchDoc, Main.SchDoc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]
2024-08-23 add M66
    [GSM.SchDoc]
2024-08-23 add LED Indicator
    [GSM.SchDoc]
2024-08-23 add Simcard
    [GSM.SchDoc, aLCD.SchDoc]
2024-08-23 add UART Voltage Deivder
    [GSM.SchDoc]
2024-08-23 add UART harness
    [AVR_RCS.PrjPcb, Controller.SchDoc, GSM.SchDoc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]
2024-08-23 add GSM Supply Filters
    [GSM.SchDoc]
2024-08-23 relocate blockes
    [Main.SchDoc]
2024-08-25 add crystal to Controller
    [Controller.SchDoc]
2024-09-26 add Crystal
    [Controller.SchDoc]
2024-09-26 add Zener
    [GSM.SchDoc]
2024-09-26 Add 220V Detector
    [Inputs.SchDoc]
2024-09-26 Add input Connector
    [Inputs.SchDoc]
2024-09-26 add Motor Detector
    [Inputs.SchDoc]
2024-09-26 add Swithc Harness
    [AVR_RCS.PrjPcb, Controller.SchDoc, Inputs.SchDoc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]
2024-09-26 add AHT20
    [Controller.SchDoc]
2024-09-26 add Remote
    [Remote.SchDoc]
2024-09-26 add learn SW
    [Controller.SchDoc, Main.SchDoc, Remote.SchDoc]
2024-09-26 add eclosure
    [Controller.SchDoc, Inputs.SchDoc, aLCD.SchDoc]
2024-10-10 Components placement
    [AVR_RCS.PrjPcb, Controller.SchDoc, GSM.SchDoc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]
2024-10-10 Change some 1206 cap to 0805
    [Supply.SchDoc]
2024-10-30 reArrange Designators
    [AVR_RCS.PrjPcb]
2024-10-30 add PCB CoutOut
2025-02-21 update all components with aKaReZa Library
    [AVR_RCS.PrjPcb, Controller.SchDoc, GSM.SchDoc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]
2025-03-08 add Document and preprare PCB for Ordering
    [AVR_RCS.PrjPcb, GSM.SchDoc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]
2025-03-10 Update Files
    [PCB.PcbDoc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]
2025-03-10 Update documents
    [AVR_RCS.PrjPcb, Main.SchDoc, RCS_AVR_V1-0.PcbDoc]
2025-06-05 aKaReZa 109
    [AVR_RCS.PrjPcb]
2025-10-17 add millis, update alcd and akareza
2025-10-17 add blinky antenna
2026-11-04 Read Sensor Data
2026-11-04 add sensor data to STS Msg
2026-11-04 PowerOn msg
2026-11-11 add gitHash, Sensor Fault, Remove a Warning
